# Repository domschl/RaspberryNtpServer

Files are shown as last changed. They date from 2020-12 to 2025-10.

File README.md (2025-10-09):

# GPS disciplined Stratum-1 NTP Server with Raspberry PI - a HowTo

Stratum-1 NTP time server with Raspberry Pi, GPS and Chrony: 

- how to build a precision time server.
- (optional) [how to add a 4x20 LCD to display](src) server status and GPS and PPS information.

<div align="right">
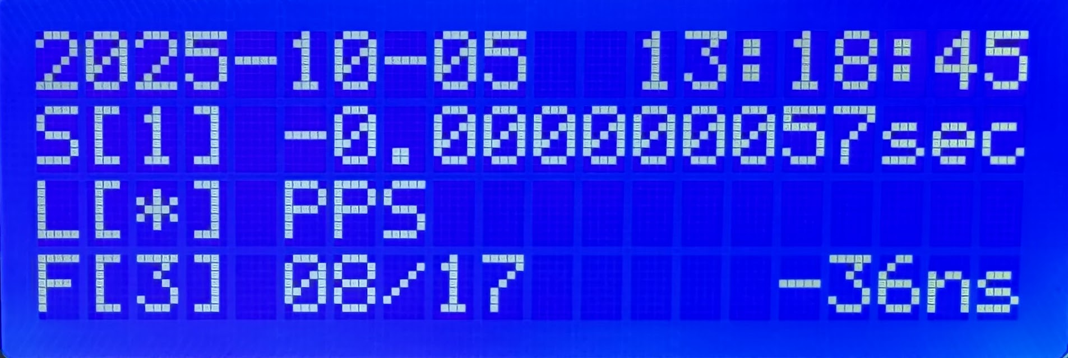
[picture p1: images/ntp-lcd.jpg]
<br>
<em>Optional display shows PPS lock, see <a href=https://github.com/domschl/RaspberryNtpServer/tree/main/src#notes-on-the-display-information>explanation</a></em>
</div>

## Requirements - Hardware

- Raspberry Pi

While you can use any model of Raspberry Pi to implement a Stratum-1 NTP server with GPS, the best choice
is Raspberry Pi 4, due to 1Gbit network interface and fast hardware for lowest possible latencies.

  - Using a Raspberry Pi 5 gives two additional advantages, but has changed the configuration of the serial port.

    - Support for the inbuilt hardware real time clock (RTC) that comes with the Raspberry Pi 5
    - Support for the PTP protocol, which allows to transmit precision time information via ethernet hardware
    - When connecting the GPS receiver via serial port, the new default is not to use the RX, TX pins on the 40pin connector, but the new three-pin UART connector. To use the 40-pin connector a special configuration is needed.

Both options are of limited advantage for most settings: the hardware clock is only useful for providing time during the first few seconds after boot (and if both GPS _and_ network are inaccessible), and PTP is a time standard requiring IEEE1588-enabled hardware everywhere and provides no advantages over NTP/chrony in most settings. Both however are documented below (See `chrony` configuration, PTP-chapter).

- GPS module

  * Adafruit GPS hat: [Adafruit ultimate GPS hat](https://www.adafruit.com/product/2324)
  * GPS module with serial output and PPS signal: [Adafruit GPS module](https://www.adafruit.com/product/746)
  * GPS module with USB, SMA connector and PPS: [Keystudio GPS module](https://wiki.keyestudio.com/KS0319_keyestudio_GPS_Module)
  * Cheap NEO6 modules: [Aliexpress NEO6](https://www.aliexpress.com/w/wholesale-neo6.html))

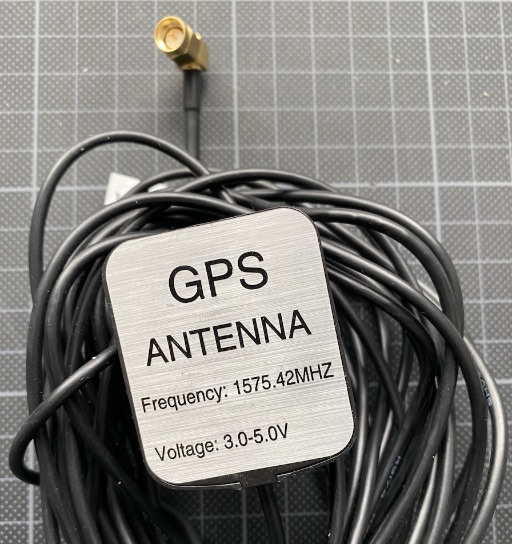
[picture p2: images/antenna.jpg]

  
* Active GPS antenna

When selecting a GPS antenna, make sure to get an active antenna with 3-5V power input. Passive antennas often look similar, but reception quality is far worse at similar cost.

### Antenna adapters

Some boards have uFL antenna connectors, whereas almost all external active antennas use SMA, so you might need an uFL to SMA adapter:

* [Adafruit uFL to SMA adapter](https://www.adafruit.com/product/851)
* [Various uFL to SMA adapters](https://www.aliexpress.com/item/4000166668788.html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,searchweb201602_,searchweb201603_)

### To check

#### Is external antenna selected?

Some GPS modules come with a passive antenna and and external antenna plug. Check the description of your board to find out what's needed to use the external antenna. The Keystudio GPS module listed above for example, requires the removal of capacitor C2 in order to activate the external antenna.

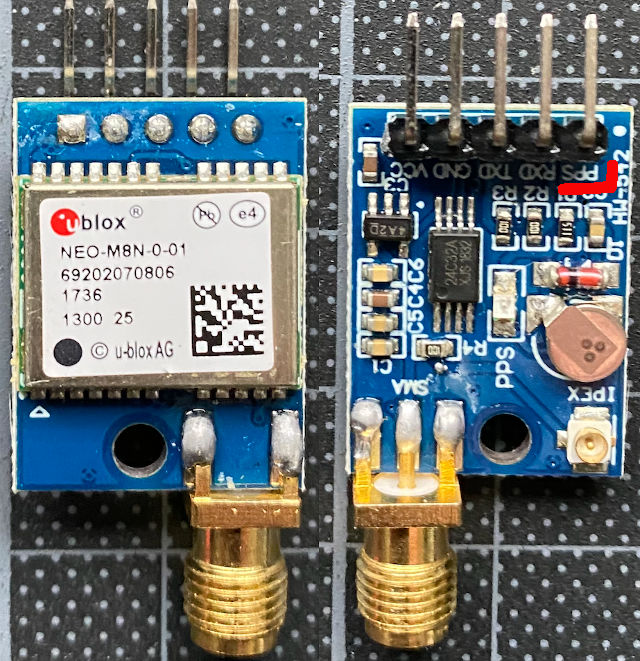
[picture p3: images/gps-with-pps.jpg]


#### PPS signal easily accessible?

Make sure your GPS module has an accessible output for the PPS signal. (Red mark on image)

If you are using a GPS Hat that plugs into the Raspberry IO connector, check the documentation to which GPIO pin the PPS signal is connected. Adafruit's Hat uses GPIO 4.

#### USB vs serial

When not using a Pi Hat, decide between USB- and serial connection.

USB-Connection:
* No extra cables for Vcc, GND, Tx, Rx are needed: both powersupply and communication goes over USB.
* No modification of Raspberry's serial console is needed, easier software installation
* Example: [Keystudio GPS module](https://wiki.keyestudio.com/KS0319_keyestudio_GPS_Module)

Serial connection:
* Usually cheaper, if a module is purchased.
* All Pi Hats use serial connections.
* Raspberry serial console needs to be disabled
* Sometimes, bluetooth needs to be disabled.
* Raspberry Pi 5 changed the default serial connection to the 3-pin UART connector by default.

### Recommended setup

* Raspberry PI 4 (or 5)
* Either GPS hat (e.g. adafruit ultimate GPS hat + uFL to SMA-Adapter) or USB-GPS-Module with PPS output (e.g. keystudio gps module)
* Active GPS antenna with SMA connector and 3-5V

### Most cost-efficient setup

NEO6 GPS modules are available at very low cost (1-2Eur) at chinese dealers (Aliexpress) and are perfectly usable as long as they allow connecting an active external GPS antenna and provide a PPS signal.

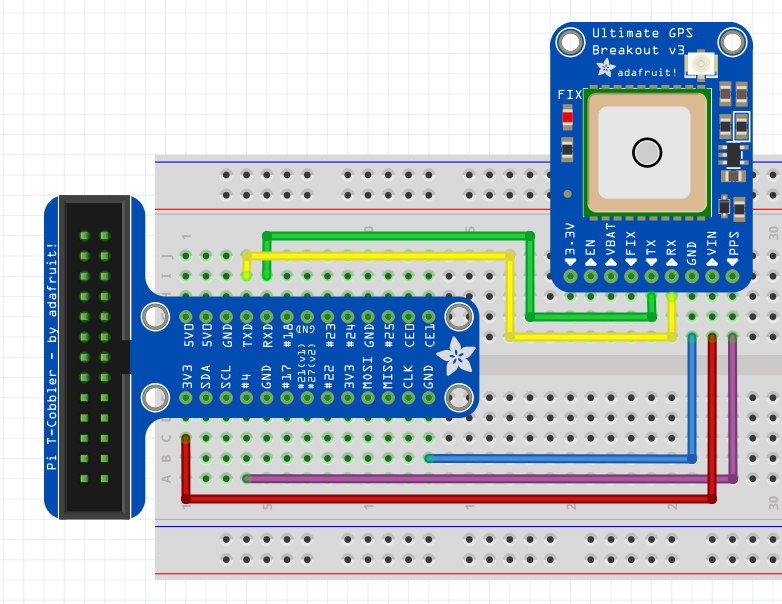
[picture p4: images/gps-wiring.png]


_Typical wiring between GPS module and Raspberry Pi connector._

> **Note:** If your GPS module is connected via USB, you only need to connect the PPS connector on the GPS module to GPIO 4 on the Raspberry. Power (Vin), Gnd and Tx/Rx are handled via USB.

> **Note:** The Raspberry Pi 5 has a new connector for the serial port that is used by default instead of the Pins RX, TX on the diagram:

#### Raspberry PI 5 serial connection changes

- Either use _new the three-pin UART connector_, which is used by default for serial communication,
- or reconfigure the serial ports by editing `/boot/firmware/config.txt` and adding the lines:

```
dtparam=uart0
dtparam=uart0_console
```

Documentation for those options is currently in a disarray for Raspberry Pi 5, so some research might be required. See discussion in [#6](https://github.com/domschl/RaspberryNtpServer/issues/6). Also this [video on Raspberry Pi 5 Serial Port](https://www.youtube.com/watch?v=27p4XHE3iyw) usage might be helpful.

### Test

**Before you continue with software:** At this point, the GPS module should be connected to the Raspberry Pi and the active antenna. Power up the Raspberry Pi, and check that the GPS module receives the GPS signal (the antenna must have unhindered access to the open sky, it does *not* work indoors!).

If reception is ok, a led ("FIX" or "PPS") should start blinking on your GPS module. 

Check the documentation for your specific hardware how "FIX" is signaled:

- The Adafruit module blinks once per second if there is no fix and once every 10 seconds when there is a fix.

### More information

* Adafruit has an excellent [GPS guide](https://learn.adafruit.com/adafruit-ultimate-gps) for their ultimate GPS module.

### Professional / Lab considerations: PTP precision time protocol (OPTIONAL)

If you are using laboratory equipment that uses PTP (precision time protocol) information (IEEE 1588), then you will need to use the Raspberry Pi 5 and make sure that your network switches are IEEE 1588 capable. Note that most consumer switches are not IEEE 1588 capable and cannot be used to set up a PTP network. See below (PTP chapter) for setup details and hardware tests.

PTP is completely optional and not required in a network in order to have excellent results with your Raspberry Pi NTP server!

## Software

> **Note:** _(Optional info)_ The original repository of `chrony` at <https://chrony.tuxfamily.org/> seems to be of low availability. In case of problems, use the mirror at <https://github.com/mlichvar/chrony)> if you want to reference the original `chrony` sources at some point.

### Raspberry Pi OS preparations

Supported are Raspberry Pi OS Bookworm and Trixie

#### Update Notes

If you are updating from 'Bookworm' to 'Trixie', and you are using the display, you will need to update the [display software](https://github.com/domschl/RaspberryNtpServer/tree/main/src) and its dependencies.

#### Serial port console (skip, if connected via USB)

If your GPS board is connected via serial connection (Rx/Tx), you need to "free up" Raspberry's serial port, which by default is used to connect a serial (debug) console. We need to disable that console to prevent it from interferring with the GPS module. 

This is *not* needed, if your module is connected via USB.

How to disable the serial console on Raspberry variies greatly depending on hardware revision and Linux flavour used. A few examples:

##### For Raspberry Pi 4 with Raspberry Pi OS:

1. Start raspi-config: `sudo raspi-config`.
2. Select option 3 - Interface Options.
3. Select option P6 - Serial Port.
4. At the prompt Would you like a login shell to be accessible over serial? answer 'No'
5. At the prompt Would you like the serial port hardware to be enabled? answer 'Yes'
6. Exit raspi-config and reboot the Pi for changes to take effect.

See ["Disable Linux serial console"](https://www.raspberrypi.org/documentation/configuration/uart.md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,Select%20option%20P6%20%2D%20Serial%20Port) at raspberrypi.org.

Older versions of `raspi-config` hide the same serial options under "Advanced options"

##### Other linux distributions and manual configuration

> **Note:** Recent Raspberry Pi OS has __moved__ the location of kernel config files from `/boot/` to `/boot/firmware/`. Adapt the following paths according to your OS version (If moved, a note is left at the old `/boot/` location.

1. Edit `/boot/firmware/cmdline.txt` and remove references to the serial port `ttyAMA0`. E.g. remove: `console=ttyAMA0,115200` and (if present) `kgdboc=ttyAMA0,115200`.
2. Disable getty on serial port. `sudo systemctl disable getty@ttyAMA0` or, on some Linux distris: `sudo systemctl disable serial-getty@ttyAMA0`
3. Enable uart in `/boot/firmware/config.txt`, add a line `enable_uart=1`
4. For RPI 3 or later disable bluetooth via overlay, add another line to `/boot/firmware/config.txt`: `dtoverlay=pi3-disable-bt-overlay`. In some versions, this is done by *enabling* the overlay `dtoverlay=pi3-miniuart-bt` which disables bluetooth and reestablishes standard serial.

See: ["Raspberry Pi 3, 4 and Zero W Serial Port Usage"](https://www.abelectronics.co.uk/kb/article/1035/raspberry-pi-3-serial-port-usage).  

#### Test serial / USB output of GPS

Do a `cat` on your serial port (e.g. `cat /dev/ttyS0`), or, for USB `cat /dev/ttyACM0` or `cat /dev/ttyUSB0`, and you should receive an output like:

```
$GPGGA,1413247.000,48432.1655,N,01342323.7322,E,1,06,1.340,2505.5,M,347.6,M,,*69
$GPGSA,A,3,123,303,248,205,037,415,,,,,,,1.59,1.340,0.90*049
```

## Setting up GPSD

Once you successfully receive output from your GPS module, next step is to install `gpsd` via your package manager.

For Raspberry Pi OS (and Ubuntu and Debian variants), that would be:

```bash
sudo apt install gpsd
```

Edit `/etc/default/gpsd`:

For serial connections (use your device name as tested above):

```
GPSD_OPTIONS="-n -G"
DEVICES="/dev/ttyS0"
USBAUTO="false"
```

For USB connections (again use your actual device name):

```
GPSD_OPTIONS="-n"
DEVICES="/dev/ttyACM0"
USBAUTO="true"
```

Enable and start `gpsd` with:

```
sudo systemctl enable gpsd
sudo systemctl start gpsd
```

Now use `cgps` or `gpsmon` to make sure that you are receiving GPS information and time.

`cgps` should display `Status: 3D fix (xx secs)`. Do not continue until you have a stable GPS fix.

## Setting up PPS

The serial or USB connection to the GPS module alone does not allow precise time synchronisation. The slow communication has latencies somewhere between 50ms to 200ms, much too high latency for precision time servers.

This is compensated by the PPS signal that is directly connected to Raspberry PI's GPIO 4 (you can use other GPIO pins, simply adapt this correpondingly below).

We need to enable a special kernel driver and overlay in order to receive this once-per-second GPS synchronised pulse as precisely as possible. The location of config files for kernel modules and options has changed recently (2024-03)!

### Current Raspberry Pi OS 'Bookworm' (since 2024-03) and 'Trixie' (since 2025-10)

You'll find that `/boot/config.txt` just contains a note that file content has moved to `/boot/firmware/config.txt`. 

1. Edit `/boot/firmware/config.txt` and add a line `dtoverlay=pps-gpio,gpiopin=4`. (Editing `cmdline.txt` is no longer necessary)
2. Edit `/etc/modules-load.d/raspberrypi.conf` and add two lines with `pps-gpio` and `pps-ldisc`, to load the required kernel modules

### Older versions of Raspberry Pi OS and other distris

if your `/boot/config.txt` does __not__ contain a note that content has moved to `/boot/firmware/config.txt`:

1. Edit `/boot/cmdline.txt` and add ` bcm2708.pps_gpio_pin=4` at the end of the line. (Might not be necessary)
2. Edit `/boot/config.txt` and add a line `dtoverlay=pps-gpio,gpiopin=4`. (Depending on your distri, either 1. or 2. is necessary, but it doesn't seem to hurt to do both).
3. Edit `/etc/modules-load.d/raspberrypi.conf` and add two lines with `pps-gpio` and `pps-ldisc`, to load the required kernel modules

After a reboot, a new device `/dev/pps0` should exist, and `dmesg` should show something like:

```
[    7.528565] pps_core: LinuxPPS API ver. 1 registered
[    7.530144] pps_core: Software ver. 5.3.6 - Copyright 2005-2007 Rodolfo Giometti <giometti@linux.it>
[    7.540372] pps pps0: new PPS source pps@4.-1
[    7.542012] pps pps0: Registered IRQ 166 as PPS source
[    7.550775] pps_ldisc: PPS line discipl43ine registered
```

Now use `ppstest` (you might need to install `pps-utils` or `pps-tools` depending on your distri):

`sudo ppstest /dev/pps0`

You should see an output like:

```
trying PPS source "/dev/pps0"
found PPS source "/dev/pps0"
ok, found 1 source(s), now start fetching data...
source 0 - assert 1606833766.999998552, sequence: 341090 - clear  0.000000000, sequence: 0
source 0 - assert 1606833767.999998573, sequence: 341091 - clear  0.000000000, sequence: 0
source 0 - assert 1606833768.999998751, sequence: 341092 - clear  0.000000000, sequence: 0
```

`assert` and `sequence` should both increment by 1 for each line.

Once you receive a PPS signal and GPSD is configured, continue.

### Access permissions for `/dev/pps0`

Some linux distribution only allow `root` to read or access `/dev/pps0`. This is no issue, if only root services want to access `/dev/pps0`. Note that recent versions of `chronyd` drop privileges after start, and then might not be able to access `/dev/pps0` anymore. See below for solutions (`udev` or running `chronyd` as root.)

### Timeouts with Raspberry Pi OS 64-bit 2023-03 onwards

**Note:** This problem seems to be fixed with current Raspberry Pi OS 'bookworm' and 'trixie' releases (2023-12 status).

`sudo ppstest /dev/pps0` yields:

```
found PPS source "/dev/pps0"
ok, found 1 source(s), now start fetching data...
source 0 - assert 1679340614.003464678, sequence: 84623 - clear  0.000000000, sequence: 0
time_pps_fetch() error -1 (Connection timed out)
```

See issue [6](https://github.com/domschl/RaspberryNtpServer/issues/6) for the ongoing discussion.

## Setting up Chrony as time-server

> **Note:** Before you setup `chrony`, make sure you completed `gpsd` configuration and that `gpsd` is running ok, and that you have a valid PPS signal at `/dev/pps0`.

> **Note:** Especially when using Raspberry Pi 5 (with new features PTP and RTC), it is recommended to use the standard Raspberry Pi OS, which comes with a chrony version, that is aware of the Raspberry Pi hardware.

Recent chronyd versions drop root privilege after start (check for the `-u` option in `chronyd.service` to see the user that will be used to run `chronyd`). If `/dev/pps0` is not accessible for that user, pps won't work. There are two solutions: either use a version of chronyd that doesn't drop privileges and runs as root, or setup a `udev` rule that allows access to `/dev/pps0` for the process-user of `chronyd`.

If you [compile](https://chrony.tuxfamily.org/doc/3.5/installation.html), [mirror](https://github.com/mlichvar/chrony/blob/master/doc/installation.adoc) `chrony` yourself, there is an option `--disable-privdrop` for `configure`. See `configure -h` for all options for building `chrony`.

### `udev` rules example

Udev rules are tricky and depend on the user of the `chronyd` process and the type of connection your are using.

Create a file `/etc/udev/rules.d/pps-sources.rules` starting with this example (which works with Raspberry Pi OS), which you will need to modify to your configuration:

```
KERNEL=="pps0", OWNER="root", GROUP="_chrony", MODE="0660"
KERNEL=="ttyS0", RUN+="/bin/setserial -v /dev/%k low_latency irq 4"
```

To activate those new `udev` rules, either reboot, or use: `sudo udevadm control --reload-rules && sudo udevadm trigger`.

This assumes `_chrony` being the user/group of the `chronyd` process (check with `ps aux | grep chronyd`) and a serial connection (here `/dev/ttyS0`) being used.[^1]

### Installation of `chrony`

Install `chrony`, an alternative NTP server that in my experience results in higher precision time servers than good old ntpd.

Make sure that no other time server (`ntdp`, `systemd-timedated`) is active, e.g.

```
sudo systemctl disable systemd-timedated
sudo systemctl stop systemd-timedated
```

Depending on you distri and chrony versione, the config is either `/etc/chrony/chrony.conf` or `/etc/chrony.conf`, edit the file and add two lines:

```
refclock PPS /dev/pps0 lock GPS
refclock SHM 0 refid GPS precision 1e-1 offset 0.0 delay 0.2 noselect
```

> **Note:** See [man chrony.conf](https://chrony-project.org/doc/4.4/chrony.conf.html) for more details

This uses a shared memory device `SHM` to get unprecise time information from GPSD (low precision, marked as `noselect`, so that chrony doesn't try to sync to serial time data). This unprecise time information is then synchronised with the much more precise PPS signal.

#### Additional Raspberry Pi 5 features

Verify that `chrony.conf` contains the following line (standard in Raspberry Pi OS version):

```
# This directive enables kernel synchronisation (every 11 minutes) of the
# real-time clock. Note that it can't be used along with the 'rtcfile' directive.
rtcsync
```

If you want to transmit PTP hardware timestamps via ethernet, add:

```
hwtimestamp *
```

See below for some more details on PTP.

#### All version, continued

Now enable and start `chrony`:

```
# Note: Some distributions use `chronyd` instead of `chrony`, so replace, if necessary:
sudo systemctl enable chrony
sudo systemctl start chrony
```

Verify that `chrony` started ok with `sudo systemctl status chronyd`. One possible error is a fatal message that `chronyd has been compiled without PPS support`. If that's the case (e.g. Manjaro ARM 64bit), you either need to [compile chrony yourself](https://chrony.tuxfamily.org/doc/2.4/installation.html), [mirror](https://github.com/mlichvar/chrony/blob/master/doc/installation.adoc), or switch to another distri.

Then start the chrony console with `chronyc`. At the `chronyc>` prompt, enter:

`sources`

```
chronyc> sources
210 Number of sources = 6
MS Name/IP address         Stratum Poll Reach LastRx Last sample               
===============================================================================
#* PPS0                          0   4   377    13   -138ns[ -108ns] +/-  120ns
#? GPS                           0   4   377    13  -4624us[-4624us] +/- 2148us
^- sismox.com                    3  10   377    15   -179us[ -179us] +/-   81ms
^- ntp.fra.de.as206479.net       2  10   377   749  +4235us[+4238us] +/-   16ms
^- mail.trexler.at               2  10   377  1114  +1190us[+1193us] +/-   13ms
^- ntp2.hetzner.de               2  10   377    59   -411us[ -411us] +/-   32ms
chronyc> 
```

**Note:** See [man chronyc](https://chrony-project.org/doc/4.0/chronyc.html) for more details

<div align="right">
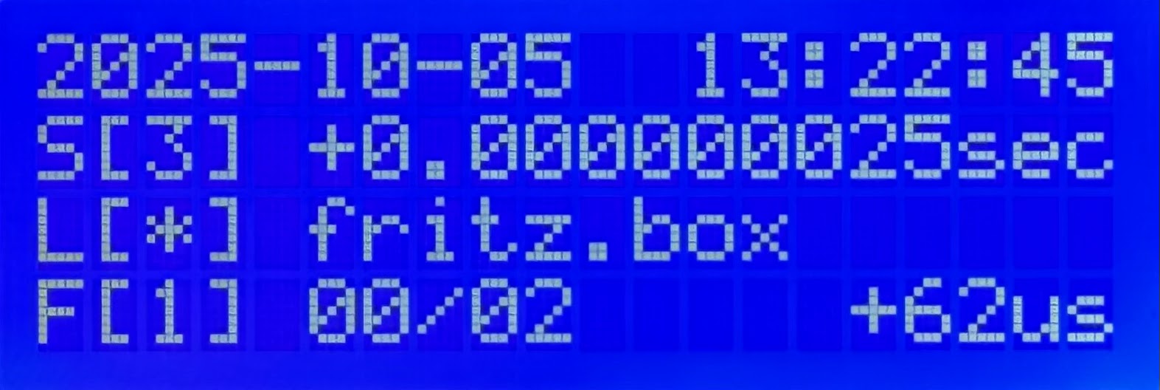
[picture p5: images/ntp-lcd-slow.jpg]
<br>
<em>Before PPS lock, stratum 3</em>
</div>

If all went well, you should see a `PPS` device marked with `#*`, indicating the active time source. Error should be in nanosecond range (`-138ns[ -108ns] +/-  120ns`). `#?` indicates an unusable time source, `^-` a usable but unused source.

### Synchronizing the offset between serial time information and PPS

The PPS signal is only used, if the divergence between the slow serial/USB time information and the precise PPS signal is less than 200ms. If your PPS device stays on `#?` (unusable), and you are sure that gpsd is receiving valid GPS signals and `ppstest` shows a correct PPS signal, then we need to tune the offset between serial time information and PPS. 

In `chronyc`, enter `sourcestats`

```
chronyc> sourcestats
210 Number of sources = 9
Name/IP Address            NP  NR  Span  Frequency  Freq Skew  Offset  Std Dev
==============================================================================
...
GPS                        40  22   626     -4.310      9.467    512ms  2474us
...
```

the important field is `offset` of `GPS`: if that is larger 200ms, PPS cannot sync to GPS.

Wait a few minutes for the offset to stabilize, note it's value, and edit `/etc/chrony.conf` (or `/etc/chrony/chrony.conf`), and change the offset in the second line with the value above, converted to seconds (512ms are 0.512 sec in this case):

```
refclock PPS /dev/pps0 lock GPS
refclock SHM 0 refid GPS precision 1e-1 offset 0.512 delay 0.2 noselect
```

<div align="right">
<br>
<em>After PPS lock, stratum 1</em>
</div>

> **Note:** A value of `offset 0.0` seems to prevent synchronisation for some versions of chrony, so use some small non-zero value instead, if a value close to 0 is required for your installation.

Restart `chrony` with `sudo systemctl restart chronyd`, and check `chronyc` again:

After some time the output of `sourcestats` should show a much better offset for GPS:

```
chronyc> sourcestats
210 Number of sources = 9
Name/IP Address            NP  NR  Span  Frequency  Freq Skew  Offset  Std Dev
==============================================================================
PPS0                       12   5   179     +0.000      0.003     +1ns   102ns
GPS                        40  22   626     -4.310      9.467  -8600us  2474us
```

and `sources` should now show PPS as active, marked with `#*`.

Use `chronyc` and command `tracking` to get information about the precision of your new time server:

```
chronyc> tracking
Reference ID    : 50505330 (PPS0)
Stratum         : 1
Ref time (UTC)  : Tue Dec 01 15:17:22 2020
System time     : 0.000000032 seconds slow of NTP time
Last offset     : -0.000000059 seconds
RMS offset      : 0.000000103 seconds
Frequency       : 2.167 ppm fast
Residual freq   : -0.000 ppm
Skew            : 0.005 ppm
Root delay      : 0.000000001 seconds
Root dispersion : 0.000025110 seconds
Update interval : 16.0 seconds
Leap status     : Normal
```

* For more information, check the [chrony PPS documentation](https://chrony.tuxfamily.org/faq.html#_using_a_pps_reference_clock), [mirror](https://github.com/mlichvar/chrony/blob/master/doc/faq.adoc#using-pps-refclock)

### Making you new precision time server available on the network

By default, chrony allows only local access, use `allow` in `/etc/chrony.conf` to allow access in your local network, e.g.:

```
allow 192.168/16
```

To be able to administer the chrony time server over the net, add:

```
cmdallow 192.168/16
```

### Remote testing

The tool `sntp` (available by default on macOS, part of the `ntp` package for most linux distributions)
allows for simple remote testing:

> **Note:** when installing `ntp` for getting access to the `sntp` tool, make sure that you do not accidentally activate the `ntp` server which will conflict with your chrony installation.

```bash
sntp <ip-or-hostname-of-raspberry-chrony-server>
```

yields (mac connected via WLAN):
```bash
sntp chronotron
# Output:
+0.011341 +/- 0.002986 chronotron 192.168.178.3
```

More information is available with `sntp -d`

```bash
sntp -d chronotron
# Output:
sntp_exchange {
        result: 0 (Success)
        header: 24 (li:0 vn:4 mode:4)
       stratum: 01 (1)
          poll: 00 (1)
     precision: FFFFFFE8 (5.960464e-08)
         delay: 0000.0001 (0.000015259)
    dispersion: 0000.000B (0.000167847)
           ref: 50505300 ("PPS ")
    ...
}
```

Interesting information is for example:

- `ref: xx.. ("PPS")`
- `precision: (5.9e-08)`

### Raspberry Pi 5 and the PTP precision time protocol via ethernet  [OPTIONAL for SPECIAL SETTINGS]

> **Note:** The PTP precision time protocol (IEEE 1588) is of limited use for home networks, it requires that every component (server, network switch, client) have hardware support for IEEE 1588 which is not the case for most consumer hardware. You cannot use PTP if a single component does not support it.

An excellent overview over PTP, it's relation to NTP can be found at Redhat's [_combining ptp and ntp_](https://www.redhat.com/en/blog/combining-ptp-ntp-get-best-both-worlds) article.
If you are not in a professional lab environment, _you might not need PTP at all!_

#### Preparations

You can verify that hardware timestamping is active by executing `sudo systemctl status chrony` right after start of chrony. You should see something like:

```
Dec 20 15:17:15 chronotron chronyd[9525]: chronyd version 4.3 starting (+CMDMON +NTP +REFCLOCK +RTC +PRIVDROP +SCFILTER +SIGND +ASYNCDNS +NTS +SECHASH +IPV6 -DEBUG)
Dec 20 15:17:15 chronotron chronyd[9525]: Enabled HW timestamping on eth0
```

To verify if a chrony client or server can support the PTP protocol, use:

```bash
ethtool -T eth0
```

You should see something like:

```
Time stamping parameters for eth0:
Capabilities:
        hardware-transmit
        software-transmit
        hardware-receive
        software-receive
        software-system-clock
        hardware-raw-clock
PTP Hardware Clock: 0
Hardware Transmit Timestamp Modes:
        off
        on
        onestep-sync
Hardware Receive Filter Modes:
        none
        all
```

Required are the `hardware-transmit` and `hardware-receive` options.

#### PTP software

Make sure the kernel module `ptp` is loaded (`sudo modprobe ptp`). In addition, you will need `linuxptp` on both server and client. On the
raspberry, it can be installed with `sudo apt install linuxptp`

On the raspberry server:

```
sudo ptp4l -i eth0 ptp0 -m -2
```

The ptp server should start and output something like:

```
ptp4l[6491.320]: selected /dev/ptp0 as PTP clock
ptp4l[6491.364]: port 1: INITIALIZING to LISTENING on INIT_COMPLETE
ptp4l[6491.364]: port 0: INITIALIZING to LISTENING on INIT_COMPLETE
ptp4l[6498.761]: port 1: LISTENING to MASTER on ANNOUNCE_RECEIPT_TIMEOUT_EXPIRES
ptp4l[6498.761]: selected local clock d83add.fffe.b1d67a as best master
ptp4l[6498.761]: port 1: assuming the grand master role
```

Now, on a client that has a network card with IEEE 1588 support (check with `ethtool -T eth0` that hardware-transmit is supported) and is connected either directly or via a PTP-IEEE 1588 enabled switch (hint: most consumer network switch _do not support the required protocol_!):

again make sure module `ptp` is loaded, install `linuxptp` and:

```
sudo ptp4l -i enp86s0 -m -2 -s
```

the `-s` option enables slave mode for the client.

If it works, you should see something like:

```
ptp4l[82232.615]: selected /dev/ptp0 as PTP clock
ptp4l[82232.689]: port 1 (enp86s0): INITIALIZING to LISTENING on INIT_COMPLETE
ptp4l[82232.689]: port 0 (/var/run/ptp4l): INITIALIZING to LISTENING on INIT_COMPLETE
ptp4l[82232.689]: port 0 (/var/run/ptp4lro): INITIALIZING to LISTENING on INIT_COMPLETE
ptp4l[82233.617]: port 1 (enp86s0): new foreign master d83add.fffe.b1d67a-1
ptp4l[82237.617]: selected best master clock d83add.fffe.b1d67a
ptp4l[82237.617]: port 1 (enp86s0): LISTENING to UNCALIBRATED on RS_SLAVE
ptp4l[82239.619]: master offset   59823 s0 freq  -51831 path delay    4413
ptp4l[82240.618]: master offset   59749 s1 freq -2154985 path delay   4159
ptp4l[82241.618]: master offset   59733 s2 freq  +91748 path delay   4159
```

If you get any `received SYNC without timestamp` or similar with `DELAY`, then somewhere in your transmission chain there is non-IEEE 1588 hw, and the sync doesn't work.

### Further optimizations in `chrony.conf`

* `lock_all` to make sure chrony is always in memory.
* `local stratum 1` to signal precision time.
* `allow` without any address simply allows all networks. (Including external access, if your machine is connected to the internet!)

For more, check the [official chrony documenation](https://chrony.tuxfamily.org/doc/4.0/chrony.conf.html), [mirror: chrony.conf](https://github.com/mlichvar/chrony/blob/master/doc/chrony.conf.adoc).

## Add a 4x20 hardware LCD display

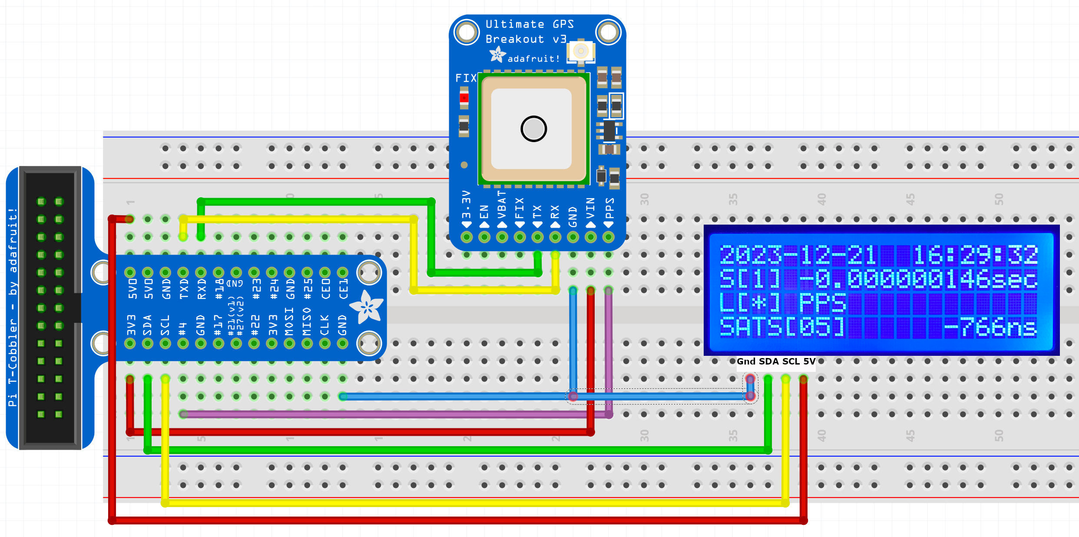
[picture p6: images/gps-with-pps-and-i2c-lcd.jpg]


Optionally, you can use [this sub-project to a status display to the Raspberry Pi](src).

## History

- 2025-10-09: Support for Adafruit I2C hardware using MCP23008 added, thanks @Bigjohn4 for testing support.
- 2025-10-05: Changed display software to use python3-gps library, thanks [rglidden](https://github.com/rglidden)
- 2024-04-30: Changes to Raspberry Pi 5 serial Port configuration, see [6](https://github.com/domschl/RaspberryNtpServer/issues/6), thanks @aGGreSSiv for figuring out the issue!
- 2024-03-06: Update: location of `/boot/config.txt` has changed to `/boot/firmware/config.txt`. Thanks to @Nebulosa-Cat for the information!
- 2023-12-21: Cleanup for the display software, display current stratum level (thanks @Lefuneste83, see [#7](https://github.com/domschl/RaspberryNtpServer/issues/7)), implemented logging.
- 2023-12-20: Raspberry 5 and suport for RTC and PTP precision time protocol how-tos.
- 2023-07-11: Documentation fixes (thx. @glenne), see [#4](https://github.com/domschl/RaspberryNtpServer/issues/4) for details. Mirror links for `chrony` added.
- 2023-02-24: Added information by @cvonderstein on initial `offset 0.01` and `udev` rules, see [#1](https://github.com/domschl/RaspberryNtpServer/issues/1) for details.
- 2023-01-09: Code for 4x20 LCD display for NTP server PPS state added.

### References

- [`chrony` documentation](https://chrony-project.org/documentation.html)
- [`chrony` documentation (mirror)](https://github.com/mlichvar/chrony/tree/master/doc)

[^1]: Thanks @cvonderstein for providing this information, see [#1](https://github.com/domschl/RaspberryNtpServer/issues/1) for further discussion.

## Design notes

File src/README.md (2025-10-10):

# Simple 4x20 LCD display for Raspberry Pi NTP Server

The display shows current NTP time and date, the PPS signal locking state, Stratum level, the offset to the NTP time, the number of satellites that are currently used, and, if no PPS lock is available, alternatively the address of the time server used.

If you see an address of some time server, PPS lock is not (yet) working.

Note: the main script `chronotron.py` defines a `start_time` and an `end_time`, used to switch on the LCD backlight (at `start_time`) and switch it off at (`end_time`). If you want permanent backlight, simply set `start_time` and `end_time` to `None`.

## Hardware requirements

- Display: HD44780 2004 LCD Display 4x20 characters with I2C interface (address 0x27 is assumed by the code), use for example:
  - Adafruit [LCD 4x20](https://www.adafruit.com/product/198) and [I2C Adapter](https://www.adafruit.com/product/292), description: (https://learn.adafruit.com/i2c-spi-lcd-backpack). Advantage: Stemma QT adapter (QWIIC) that can be also added to [Raspberry PI](https://www.adafruit.com/product/4463#:~:text=The%20SparkFun%20Qwiic%20or%20Stemma%20QT%20SHIM%20for,QT%20or%20Qwiic%29%20connector%20to%20your%20Raspberry%20Pi.) for clean cabling. Note: uses MCP23008 chip requires changes to the default configuration.
  - Amazon kit [sunfounder kit](https://www.amazon.com/SunFounder-Serial-Module-Arduino-Mega2560/dp/B01GPUMP9C)
  - AliExpress kit [TZT Five Star](https://de.aliexpress.com/item/1005001679675215.html

Make sure that I2C is enable on your Raspberry PI.



Connect the LCD Display the GND, 5V and SDA and SCL pins or the Raspberry PI.

> **Note:** Raspberry PI uses 3.3V logic, and the LCD Display is connected to 5V. This _should_ not be a problem, since the lcd just receives from Raspberry PI. If you want to be on the safe side, either try to power the LCD with **3.3V**, or use a **logic-level-converter**.

> **Note:** if your display uses a different address than `0x27`, 
or if you are using a very old Raspberry that still uses `sm_bus=0`, you need to adapt:

```python
lcd = LcdDisplay(sm_bus=1, i2c_addr=0x27, cols=20, rows=4)
```

Old Raspis use `sm_bus=0`.

> **Note:** if the LCD screen looks inverted or too faint, or no output is visible at all, use the potentiometer on the adapter-board to adjust the contrast.

## Software requirements

> **Note:** Standard Raspberry Pi OS (tested with 'Bookworm' and 'Trixie') is recommended and used below

This project uses `python3-gps` and `python3-smbus` (already available on some distributions).

### Python dependencies

Install the python GPS library and smbus, if they are not already installed on your system:

```bash
sudo apt install python3-gps python3-smbus
```

Note: Previous versions of this software relied on `gps-py3`, which was not included in Raspberry Pi OS python libraries and therefore required a venv. This is no longer required. See [PR9](https://github.com/domschl/RaspberryNtpServer/pull/19) for more details on the changes. If you previously used a venv, you might need to update your systemd service file and remove the venv directories.

Note: Trixie requires update to the new dependencies, otherwise GPS satellite status is broken!

## Installation of chronotron software

0. Clone the repository

```bash
git clone https://github.com/domschl/RaspberryNtpServer
cd RaspberryNtpServer/src
```

1. Adapt configuration

Check the beginning of the file `chronotron.py`, it contains a few parameters that can be adapted:

```python
#------- CONFIGURATION PARAMETERS -----------------------
# start_time and end_time switch the display off during night-time.
# Set both to None for always-on
start_time:str|None = "07:00"
end_time:str|None = "21:00"
# I2C address of the display, usually between 0x20 (Adafruit default) and 0x27 (all others)
i2c_address_display:int = 0x27
# Set to True for Adafruit I2C adapter which uses MCP23008 chip. Enables Adafruit specific connections
# Set to False for all others which use PCF8574 
adafruit_i2c_hardware:bool = False
# Display time as UTC
display_utc_time:bool = False
# LCD display update timing: False: default, slow according to spec,
# True: update faster, low latency, exceeds specs
lcd_latency_overdrive:bool = False
# ---------------------------------------------------------
```

For Adafruit hardware that uses the MCP23008 chip and a (default) address of 0x20 make the following changes:

```python
i2c_address_display:int = 0x20
adafruit_i2c_hardware:bool = True
```

If you don't want backlight to switch off during the night, set:

start_time:str|None = None
end_time:str|None = None

Otherwise adapt the times to your liking, using 24h times and format "HH:MM"

If you want to display the time as UTC, set
# Display time as UTC
display_utc_time:bool = True

You can try to reduce LCD display latency by setting:
lcd_latency_overdrive:bool = True

2. Copy the python files to `/opt/chronotron`:

```bash
mkdir /opt/chronotron
chown -R $USER:$USER /opt/chronotron
# Now copy:
cp button.py chronotron.py i2c_lcd.py /opt/chronotron
```

3. Install the systemd service

```bash
sudo cp chronotron.service /etc/systemd/system
```

Enable the systemd server `chronotron` with:

```bash
sudo systemctl enable chronotron
sudo systemctl start chronotron
```

Check, if everthing works:

```bash
sudo systemctl status chronotron
```

If everything worked, the output should be something like:

```
chronotron.service - Display chrony statistics on 4x20 LCD
     Loaded: loaded (/etc/systemd/system/chronotron.service; enabled; preset: disabled)
     Active: active (running) since Tue 2022-10-25 14:44:17 CEST; 2 months 15 days ago
   Main PID: 370 (chronotron.py)
      Tasks: 2 (limit: 3921)
        CPU: 3d 5h 34min 24.354s
     CGroup: /system.slice/chronotron.service
             └─370 /usr/bin/python /opt/chronotron/chronotron.py

Dec 21 09:38:37 chronotron systemd[1]: Started chronotron.service - Display chrony statistics on 4x20 LCD.
Dec 21 09:38:37 chronotron chronotron.py[2628]: INFO:Chronotron:Chronotron version 2.0.0 starting
Dec 21 09:38:37 chronotron chronotron.py[2628]: INFO:Chronotron:Chrony aquired lock to time source
Dec 21 09:38:37 chronotron chronotron.py[2628]: INFO:Chronotron:Chrony receiving time source from PPS
Dec 21 09:38:37 chronotron chronotron.py[2628]: INFO:Chronotron:Chrony stratum level changed to 1
Dec 21 09:38:37 chronotron chronotron.py[2628]: INFO:Chronotron:Chrony locked to high precision GPS PPS signal
```

## Notes on the display-information

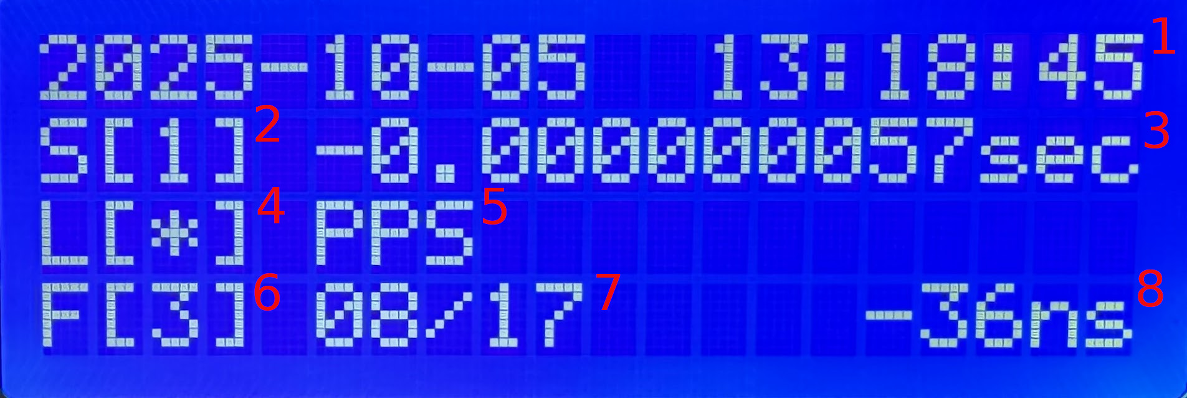
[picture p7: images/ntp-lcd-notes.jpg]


1. Time and date according to NTP
2. The current stratum level is displayed as `S[1]` for stratum level 1. 
3. Shows the output of `chronyc tracking`, entry `system time`, the time difference to the NTP reference (see below for further information).
4. `L[ ]` no lock, `L[*]` lock. A lock (`*`) indicates that time synchronisation is established, either via remote NTP servers or GPS + PPS
5. `PPS` signales that the lock is active using GPS and PPS, the server is in high-precision stratum 1 mode. If instead a hostname is displayed, then PPS is NOT active, and the network is used for time synchronisation, resulting in lower precision.
6. **New** `F[n]`, `n` is the GPS fix type: '-': unknown, 1: no fix, 2: 2D fix, 3: 3D fix.
7. **New** `nn/mm`, nn: used satellites, mm: total seen satellites, including unused ones.
8. Shows output of `chronyc sources`, the last column, "adjusted offset", of the currently active source, which is the estimated error (see below for further information)

### Further information and references

#### `chronyc tracking`

Marked with >>>nnnn.nnnn<<< is the information displayed at (2).
Here, the system is 0.000000100 seconds faster than NTP ref.

```
chronyc tracking
# sample output:
Reference ID    : 50505300 (PPS)
Stratum         : 1
Ref time (UTC)  : Tue Jul 11 07:22:07 2023
System time     : >>>0.000000100<<< seconds fast of NTP time
Last offset     : +0.000000030 seconds
RMS offset      : 0.000010080 seconds
Frequency       : 10.392 ppm fast
Residual freq   : -0.006 ppm
Skew            : 0.005 ppm
Root delay      : 0.000000001 seconds
Root dispersion : 0.000384213 seconds
Update interval : 16.0 seconds
Leap status     : Normal
```

#### `chronyc sources`

Marked with `>>>nnn<<<` is the information displayed at (6).
Here the estimated error of the PPS signal is 591ns

```
chronyc sources -v
# sample output with explanation (-v paramenter):
  .-- Source mode  '^' = server, '=' = peer, '#' = local clock.
 / .- Source state '*' = current best, '+' = combined, '-' = not combined,
| /             'x' = may be in error, '~' = too variable, '?' = unusable.
||                                                 .- xxxx [ yyyy ] +/- zzzz
||      Reachability register (octal) -.           |  xxxx = adjusted offset,
||      Log2(Polling interval) --.      |          |  yyyy = measured offset,
||                                \     |          |  zzzz = estimated error.
||                                 |    |           \
MS Name/IP address         Stratum Poll Reach LastRx Last sample               
===============================================================================
#? GPS                           0   4     0   780    +43ms[  +43ms] +/-  200ms
#* PPS                           0   4     0   782   +186ns[ +217ns] +/-  >>>591ns<<<
^? 2003:2:2:140:194:25:134:>     2  10   377   340   +141us[ +141us] +/-   17ms
^? time.ontobi.com               2  10   377   264   +139us[ +139us] +/-   13ms
^? bblock.dev                    2  10   377   631   +209us[ +209us] +/-   12ms
^? time01.nevondo.com            2  10   377   721   +181us[ +181us] +/-   28ms
^? static.33.250.47.78.clie>     3  10   377  1168   -191us[ -213us] +/-   15ms```
```

#### References

- <https://access.redhat.com/documentation/en-us/red_hat_enterprise_linux/8/html/configuring_basic_system_settings/using-chrony_configuring-basic-system-settings>
- [chronyc documentation](https://github.com/mlichvar/chrony/blob/master/doc/chronyc.adoc)

## Notes:

The `chronotron.py` systemd service checks periodically `chronyc` for NTP statistics (`chronyc` must be in the path!), and uses `gpsd` for the GPS statistics (number of satellites).

- `button.py` is currently not used.
- `i2c_lcd.py` is a buffered driver for the LCD display.
- `chronotron.service` is the systemd service file.

## History

- 2025-10-09: Support Adafruit's hardware that uses a different I2C chip, the MCP23008
- 2025-10-08: Add I2C port check on display initialization
- 2025-10-05: Update of dependencies, Trixie support (thanks [rglidden](https://github.com/rglidden))

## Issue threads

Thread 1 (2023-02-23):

Offset value of 0.0 prevents usage of GPS

cvonderstein, 2023-02-23:
Hey,

as written in the title, the offset value of `0.0` for the GPS refclock stored in `/etc/chrony/chrony.conf` (which seems to be the newer path for the config) prevents the usage of GPS as reference time. The same was discussed [here](https://chrony-users.chrony.tuxfamily.narkive.com/xJPF5Ph9/chrony-does-not-select-pps-source).

Setting it to `0.1` fixed it, I'm not sure if that breaks something or lowers the accuracy, but afterwards it at least worked for me. Maybe you want to include this in your Readme?

Addition after writing this: I saw that you mentioned correcting the offset in the config later, but for me the problem was that the GPS didn't get selected as reference clock in the first place (as it should have been as described in https://github.com/domschl/RaspberryNtpServer#setting-up-chrony-as-time-server), and the `Last sample` shown for PPS was always 0. The linked section is where I got stuck, and I didn't even get to the point of having GPS selected as the main time source.

Also, while we're at it, it would be nice to have the corresponding `udev` rules included (as figuring out how to do it when you've never worked with them before is quite pain). Just as quick reference (if you want to copy it): `/etc/udev/rules.d/pps-sources.rules` should contain

```
KERNEL=="pps0", OWNER="root", GROUP="_chrony", MODE="0660"
KERNEL=="ttyS0", RUN+="/bin/setserial -v /dev/%k low_latency irq 4"
```

This assumes the user of the `chronyd` process to be `_chrony`, which can be found out using `ps aux | grep chronyd`. Also, I'm using the serial connection here, otherwise `ttyS0` probably needs to be changed. To reload udev rules without reboot, run

```
sudo udevadm control --reload-rules && sudo udevadm trigger
```

Both cost me quite some time figuring out, so I would be happy if you include both improvements in your Readme File.

Closed 2023-02-24.

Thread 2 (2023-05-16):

Error about LCD sub project

Nebulosa-Cat, 2023-05-16:
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
I get something wrong like permission denied 、ModuleNotFoundError: No module named 'gpsd'、ModuleNotFoundError: No module named 'smbus'...

looks like somethin wrong between pip and pip3 ?

system: Pi OS 64 Lite

domschl, 2023-05-17:
You need two python packages, `smbus` and `gpsd-py3`.
I don't know Pi OS 64 Lite, but it might be good to first check if your package manager has packages with names `python3-smbus`, `python-gpsd-py3` or `python-smbus`, `python-gpsd-py3`.

If not, you can always use `pip` (`pip` and `pip3` seem to point to the same pip on your machine):

```bash
pip install smbus gpsd-py3
```

Then, before restarting the service, you could manually start the program for test:

```bash
python chronotron.py
```

You might need to use `sudo` by typing: `sudo python chronotron.py` depending on the access rights for smbus.

If you still get `module not found` errors, while having installed them with pip, you might need to repeat the installation of both modules with `sudo pip install smbus gpsd-py3`. Note that installing pip modules with `sudo` should only be done, if the modules are not available via your package manager, so check that first.

Also make sure that you are using `python3`. Simply start `python` and check the version number, it should start with `3....`.

Once you get it running, I will update the documentation, so please let me know how it goes.

Nebulosa-Cat, 2023-05-17:
>

I first check my python version ( `python -V` is 2.x.x and `python3 -V` is 3.9.2
so I do `nano ~/.bashrc` and `alias python=/usr/bin/python3.9`
now `python -V` is 3.9.2 now

and install smbus and gpsd-py3

but still get some wrong like this
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

(by the way, if use windows copy python file raw content on github and save as .py file, it will show error as "^M" at the end, looks a interpreter error, maybe need to mention just download all github file zip and use sftp upload file to Pi or use git command direct to Pi)

domschl, 2023-05-17:
That's progress: the software is now installed, but smbus fails to open.

Possible causes:

- Which raspberry hardware are you using (old raspis need different bus number)?
- Did you enable SMBUS and I2C using `raspi-config`?
- Did you try to run `sudo python chronotron.py`?

Nebulosa-Cat, 2023-05-17:
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

(before and after I open i2c in setting are same) `sudo python chronotron.py` :
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

Yes I'm not open i2c setting ( i'm only changed serieal port before), now it work and function normaly when manually use `python chronotron.py`

but if I use `sudo systemctl enable chronotron` and `sudo systemctl start chronotron` it will got `Permission denied`

if use `sudo chmod +x chronotron.py`

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

it will return fail same as use `sudo python chronotron.py`

domschl, 2023-05-17:
I've updated `chronotron.py` in the repository: That line that causes an error (`def exec(cmd):`) may have happened because of a name-clash with python's standard libs. Strangely, I never encounter this.

I've renamed the function to (hopefully!) prevent the error.

Please try again with that updated version.

Nebulosa-Cat, 2023-05-17:
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

looks still bugged, but if simply run `python chronotron.py` it work.

domschl, 2023-05-17:
So that's a good hint: the default python version for root is the old python2, which won't work!

Try an explicit path for python to start:

```bash
# verify version:
sudo /usr/bin/python
# Is there an explicit python3?
sudo /usr/bin/python3
# (results of both should be python 3.9)
# Then try again (if it exists, use `/usr/bin/python3` instead of `/usr/bin/python`
sudo /usr/bin/python chronotron.py
```

Then, if that works, we can change the `chronotron.service` file to use an explicit path.

If that works, edit the service file,

Nebulosa-Cat, 2023-05-17:
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

all fix, thank you very much, look nothing wrong now !

domschl, 2023-05-17:
Excellent!

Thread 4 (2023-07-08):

Documentation Suggestions

glenne, 2023-07-08:
Great tutorial!  I just got mine up and running.  Here's a few suggestions:

- Typo - Several references (4) to systemctl ... chronyd.  This should be just 'chrony', not 'chronyd'
- Typo - 'install gpsd via your **packet** manager.' should be 'install gpsd via your **package** manager.'
- Suggest including an example on how to install the first time an install is needed - 'sudo apt-get install gpsd'
- When adding allow 192.168/16 to chronyd.conf, one can omit the IP address and it will allow connections from any connected interface.
- A simple test from another computer can test connectivity.  On a mac, ```sntp <ip address>```, or verbose ```sntp -d <ip address>``` and it will show PPS0 being used.
- Documentation says 'If reception is ok, a led ("FIX" or "PPS") should start blinking on your GPS module.' On my Adafruit module, it blinks 1x/second if not fix and once every 10 seconds when there is a fix.

Bob-VK6ZGN, 2023-07-10:
Yes Great tutorial! I just got mine up and running.
Also using  Adafruit module and Rpi3 64bib Rasberian OS   All good
with one exception    Not sure what I am doing wrong But for SATS I just get [ -- ] when I have + 20 connected

any thoughts

domschl, 2023-07-10:
@glenne: thanks for the list, will work on that during the next days
@Bob-VK6ZGN : probably something going wrong with the `gpsd-py3` dependency. Maybe open a separate issue for this, and we can try to track this down?

glenne, 2023-07-10:
It would also be a bonus to explain what the time offset fields mean on the LCD.  e.g. NTP: and SATS

domschl, 2023-07-11:
@glenne : I've added most of the suggestions:
some remarks:
- on some distris it is actually service 'chronyd', so I added both.
- `allow` without address (and especially `cmdallow` without) can lead to unexpected [results](https://github.com/domschl/RaspberryNtpServer#further-optimizations-in-chronyconf)

Thanks for the input!

I leave this open for further discussion. Feel free to close, if completed for now.

glenne, 2023-07-11:
Looks great!  Thanks for the update.

Closed 2023-07-11.

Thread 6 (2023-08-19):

Fix for ppstest timeout

fitzy89, 2023-08-19:
With a recent update to Raspbian, it's necessary to add `arm_64bit=0` to /boot/config.txt and reboot in order to get the pps working

domschl, 2023-08-19:
I am using PPS with `arm_64bit=1` but with Manjaro. So there's probably something else going on? Maybe the access rights for `/dev/pps0` changed? Do you have some more information (e.g. `dmesg` logs?)

fitzy89, 2023-08-19:
I was following your guide using the latest Raspbian and at the point of running ppstest I was seeing timeout errors, the same issue as mentioned in this post - https://github.com/raspberrypi/linux/issues/5430 which is what led me to the above solution which seems to work fine for me.

domschl, 2023-08-20:
Interesting! A kernel bug seems to be the cause: a patch intended for 32bit got wrongly applied to 64bit. Did you try the fix suggested in:

<https://github.com/raspberrypi/linux/issues/5430#issuecomment-1557295230>

namely:

```bash
sudo rpi-update pulls/5478
```

which pulls a new 64bit kernel patch? (so `arm_64bit=1` for the patched kernel).

OdessaEyes, 2023-08-21:
For me it didn't work.
Rpi3b, 5.15.76-v7+ #1597 SMP armv7l GNU/Linux, Raspbian GNU/Linux 11 (bullseye)
sudo rpi-update or/and add arm_64bit=0 to /boot/config.txt  didn't solve the problem.

If you have any other ideas I'd be happy to try.

domschl, 2023-08-21:
@OdessaEyes : You might be encountering a different problem, since you are running 32bit Raspbian.
If your error is not timeouts on ppstest with messages like:
```
time_pps_fetch() error -1 (Connection timed out)
```
then it might be best to open a separate bug report describing what you tried?

Nebulosa-Cat, 2023-11-05:
after using `sudo rpi-update` update to `Linux Pi-Server 6.1.61-v8+ #1696 SMP PREEMPT Thu Nov  2 16:44:46 GMT 2023 aarch64`
still got `time_pps_fetch() error -1 (Connection timed out)`
maybe only `sudo rpi-update pulls/5478` will work?

Nebulosa-Cat, 2023-11-05:
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
and looks `sudo rpi-update pulls/5478` not work

romm32, 2024-01-29:
Hello. I am running the Raspberry OS, I downloaded the current version (2023-12, 32-bit version) and then ran raspi-update. I am now running an updated version from Jan 22 of 2024. I followed all the instructions with a fresh install of the OS (before starting to run the suggested commands, I ran an apt update then apt upgrade), until I got the connection timeout error in the ppstest. I added the arm64bit line to /boot/config.txt, then rebooted, and nothing happened. I also tried with the raspi-update (as previously mentioned), and a reboot, and it is still not working. I am quite new to Raspberry Pis and don't know if there is something I am doing wrong, or if the issue is a bug in the OS, but I would appreciate any help available.
Thanks in advance

domschl, 2024-01-30:
@romm32 : Non of the fixes should be necessary anymore. Which model of Raspberry Pi are you using?
Please paste the `ppstest` command together with it's output into the bug-report.
E.g. for me it looks like:

```
sudo ppstest /dev/pps0
trying PPS source "/dev/pps0"
found PPS source "/dev/pps0"
ok, found 1 source(s), now start fetching data...
source 0 - assert 1706619523.000001477, sequence: 1233465 - clear  0.000000000, sequence: 0
source 0 - assert 1706619524.000001080, sequence: 1233466 - clear  0.000000000, sequence: 0
```

I should update the instructions once we figure out what happened with your installation.

domschl, 2024-01-30:
I just checked: there is _still_ ongoing work on this bug here [Raspberry kernel pps issue 5430](https://github.com/raspberrypi/linux/issues/5430) .
One thing (if you have one of the newer models) you can try is to use Raspberry OS 64bit?

romm32, 2024-01-30:
I am using a Raspberry 4 Model B. I was first using it with Ubuntu 22, then switched to Raspberry OS and tried both for 32bit then for 64bit (versions from December 2023, following what was mentioned here). I tried the arm64bit change and it didn't work, nor did a raspi-update. The output was similar to yours, except I was getting the following line right after the "ok, found 1 source(s)...".

`time_pps_fetch() error -1 (Connection timed out)`

Given I am following this guide for my undergraduate final project, and this was one of many things left on my to-do list, I kept trying with different settings yesterday. I eventually switched to Raspberry OS for 64bit, an archive version from September 2022, and everything worked just fine (no need to try any fixes). I know it is not exactly a solution, but I guess this should be enough for the project I am working on. I was able to get chrony working, but I don't see the PPS as one of the sources. My GPS antenna is kind of bad, and I was working indoors, so I am planning on testing everything when I have a decent amount of GPS satellites available (about 10), and hopefully I will see the PPS as one of the sources.

Thank you for your quick answer, I will continue following these issues just in case someone finds another fix I could try in the future.

aGGreSSiv, 2024-02-27:
Hello,
It's an interesting problem. The NTP server is currently installed in 3 different models, pi3, pi4 and pi5. Pi4 and pi5 have the same operating system. The versions are the same. both are 64bit. (I'm not sure if it is independent of the operating system, the kernal versions are the same) However, while pi3 and pi4 work without any problems, I am experiencing this problem on pi5. I tried every suggestion I found here and online. none of them helped. As I mentioned in my previous questions, I am not very good at Linux. If everything is the same, what's left? If you find a solution or see an update released that will solve this problem, can you write it here?

Nebulosa-Cat, 2024-03-06:
after I'm fully manuly upgrade to PiOS lite Bookworm (follow this guide: https://gist.github.com/jauderho/6b7d42030e264a135450ecc0ba521bd8)

and i delete the `bcm2708.pps_gpio_pin=4` at `/boot/firmware/cmdline.txt`
(the cmdline.txt and config.txt looks move to /boot/firmware at bookworm)

now it work normally

domschl, 2024-03-06:
Thank you @Nebulosa-Cat for this information! I will update the guide.

aGGreSSiv, 2024-03-06:
it shouldn`t be this hard. @Nebulosa-Cat , i thing ill wait for to get fixed with routine updates..

ZogKarndon, 2024-04-08:
I'm having the same trouble.   I have a RPi 3b with the Adafruit Ultimate GPS Hat, running Raspberry Pi OS Lite (32 bit, release 2024-03-15) - Bookworm release

My  /boot/firmware/config.txt changes are:
```
dtoverlay=pi3-disable-bt
dtoverlay=pps-gpio,gpiopin=4
enable_uart=1
init_uart_baud=9600
arm_64bit=0
```
Still, `sudo ppstest /dev/pps0` results in:
```
trying PPS source "/dev/pps0"
found PPS source "/dev/pps0"
ok, found 1 source(s), now start fetching data...
time_pps_fetch() error -1 (Connection timed out)
time_pps_fetch() error -1 (Connection timed out)
time_pps_fetch() error -1 (Connection timed out)
time_pps_fetch() error -1 (Connection timed out)
```
Clearly I'm doing *something* wrong, but I don't know what.

Nebulosa-Cat, 2024-04-09:
@ZogKarndon
some of my `/boot/fireware/config.txt`:
```
[all]
auto_initramfs=1
enable_uart=1
dtoverlay=pps-gpio,gpiopin=4
hdmi_enable_4kp60=1
```

and my `/boot/fireware/cmdline.txt`:
```
console=tty1 root=PARTUUID=50cc6c23-02 rootfstype=ext4 fsck.repair=yes rootwait  cgroup_enable=memory cgroup_memory=1
```

and if you not get 3D-Lock yet you will recive `time_pps_fetch() error -1 (Connection timed out) ` too, might be check `cgps`

domschl, 2024-04-09:
Some additional checkpoints:

Are you loading both required kernel modules (e.g. in `/etc/modules-load.d/raspberrypi.conf`):

```
pps-gpio
pps-ldisc
```

Please try:

```bash
 sudo dmesg | grep pps
```

We can then compare the behavior of the kernel modules with this:
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
domschl, 2024-06-07:
Just to make sure:

You know that in addition to the USB connection, you need to soldier a cable to Adafruit's PPS output pin and connect that to Raspberry GPIO Pin 4?

(Sorry, I just want to make sure that connection is ok)

Reinitialized, 2024-08-28:
So I am not quite sure what happened, debugging this has left me quite tired, but after scouring through various issues on the matter, I found the following command over at https://github.com/raspberrypi/linux/issues/5430 which seems to have kicked the pps signal into gear:
`while true; do gpioset gpiochip0 17=1; gpioset gpiochip0 17=0; sleep 1; done & ppstest /dev/pps0`

I'll try to do some additional digging into exactly what made this work, but throwing it here in case it can save others some much frustrating debugging time on the matter.

owensresearch, 2025-01-03:
Is this still an issue for anyone? I am running a Raspberry Pi 3B+ with the Adafruit Ultimate GPS v3 Serial module. 64-bit OS.

I have tried the fudged PPS trick by putting GPIO 17 & 18 together and running a loop. This works for me.. actually gives me a PPS reading on gpsmon.

I have a 3D DGPS fix.
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

During intial setup/testing i was using a random old cable i had laying around and didn't realize that 2 of the pins were actually connected. So, this resulted in 5V going towards the PPS pin for about 1 hour. Could this have fried my PPS function on the Adafruit? I put a multimeter on the pin and can see 0.01V going up and down by .01 ish about every second. Assume the multimeter can't read the voltage fluctuations fast enough. Tried switching to mA and i can see spikes every second. Seems like i have a pulse.. just not sure if strong enough.

I'm no expert here.. i'm a network guy. Does this sound like my Adafruit module is fried or is this some software issue?

owensresearch, 2025-01-03:
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

Any luck? I'm about at the same place as you. Different model Pi.

Have you put any kind of multimeter on the Adafruit PPS pin? I did and it seems like i can't read the 3.3V fast enough.. but i do see a pulse of some sort with mA mode.

Would be curious to hear any progress you made.

TheSubWayKing, 2025-01-16:
Same issue with a Raspberry Pi 3 Model B+. GPS fix achieved in gpsmon and cgps, everything looks as expected other than gpsmon shows "PPS = N/A". Antenna has clear view of the sky.

sudo ppscheck /dev/pps0

returns:

 "PPS ioctl(TIOCMIWAIT) failed: 25 Inappropriate ioctl for device"

sudo ppstest /dev/pps0

returns :

"found PPS source "/dev/pps1"
ok, found 1 source(s), now start fetching data...
time_pps_fetch() error -1 (Connection timed out)"

I've had my oscope on the PPS pin and have confirmed valid PPS signal with High of 3.3v for 0.1 seconds at 1 second intervals.

I'm using a u-blox M8Q breakout module and have confirmed configuration of PPS output using the ubxtool, as measured by the oscope.

Can someone please offer some insight/resolution? Thanks

SushiFanta, 2025-01-17:
Same problem. I have not moved on to the chrony part of the guide yet.
Raspberry Pi 5, Bookworm 64-bit, Waveshare Max-M8Q GNSS hat via serial.

It looks like the config file has moved from /etc/modules-load.d/raspberrypi.conf to /etc/modules-load.d/modules.conf, so I added them there and they seem to be loading.

dmesg | grep pps
[    0.027943] pps_core: LinuxPPS API ver. 1 registered
[    0.027944] pps_core: Software ver. 5.3.6 - Copyright 2005-2007 Rodolfo Giometti <giometti@linux.it>
[    2.120182] pps pps0: new PPS source pps@4.-1
[    2.120200] pps pps0: Registered IRQ 163 as PPS source
[    2.127870] pps_ldisc: PPS line discipline registered
[    4.466885] pps pps1: new PPS source ptp0
[    7.972511] pps pps2: new PPS source ttyAMA0
[    7.972526] pps pps2: source "/dev/ttyAMA0" added

sudo ppstest /dev/pps0
trying PPS source "/dev/pps0"
found PPS source "/dev/pps0"
ok, found 1 source(s), now start fetching data...
time_pps_fetch() error -1 (Connection timed out)

cgps indicates a 3D Fix with 4 satellites and lists the time, but GPSmon shaws PPS: N/A and does not list a time. gpsd doesn't work.
gpsd:ERROR: can't run with neither control socket nor devices

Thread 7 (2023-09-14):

Improvement suggestions

Lefuneste83, 2023-09-14:
Hello

Thank you for your help in setting up this nice solution.

I have implemented most of your code for the LCD output of the chronyc status, and everything works as expected. I have a few remarks.

-In latest Linux distributions, in particular on Debian 12, you cannot "pip install" a package system wide anymore in standard.
You must restrict the installation of python packages to a venv. The proposed way to circumvent this is to use pipx to install packages system wise, but pipx only accepts programs pacakges, not libraries (which is the case for gpsd-py3 and smbus).
So the only possible solution is to manually delete the file "EXTERNALLY-MANAGED" located in /usr/lib/python3.xx/.
Considering that this venv constraint will be more and more widespread as systems get updated, you should consider updating your installation documentation.

-Considering the display itself, I believe it would be useful to replace some static information which takes some room, or to switch the content  of a line every once in a while, in particular for one missing very important information, which is the STRATUM status of the server.
If you have a synchronization issue of any kind (like a process unable to access SHM) your server can be degraded to a higher stratum level without any notice. It will still serve time internally on your LAN, but as a lower grade reference. So I believe it would be nice to have the current stratum level directly displayed as well.

I have fiddled with the code that would allow this, but haven't been successful in doing so. It would be nice to complete this ntp_offset() function to parse the stratum level as it processes the chronyc tracking output.
You could then alternate the second line of the display every 5 seconds or so with NTP: X.XXXXXXXXXsec / Stratum level : X
Or any other useful info such as RMS offset and Frequency, both of which have a slow evolution and have some level of importance.
Sorry I am not good enough in Python to work this out myself and also it would be valuable for the community.

Thanks!

Snipet of the current function below

```
def ntp_offset():
    cmd = ["chronyc", "tracking"]
    ret = exec_cmd(cmd)
    for line in ret:
        pars = line.split(":", 1)
        if len(pars) == 2:
            if pars[0].strip() == "System time":
                sub_pars = pars[1].strip().split(" ")
                if len(sub_pars) > 2:
                    val = float(sub_pars[0])
                    if "slow" == sub_pars[2]:
                        val = -1.0 * val
            return "NTP: {:+12.9f}sec".format(val)
```

Lefuneste83, 2023-09-14:
Ok forget it, I asked my new best friend Chat GPT. It took about half a second to generate the following code which I only very slightly modified to adjust the display...
I guess coders will start to get worried...

```
def ntp_offset():
    cmd = ["chronyc", "tracking"]
    ret = exec_cmd(cmd)
    ntp_val = None
    stratum_val = None
    for line in ret:
        pars = line.split(":", 1)
        if len(pars) == 2:
            key = pars[0].strip()
            value = pars[1].strip()
            if key == "System time":
                sub_pars = value.split(" ")
                if len(sub_pars) > 2:
                    ntp_val = float(sub_pars[0])
                    if "slow" == sub_pars[2]:
                        ntp_val = -1.0 * ntp_val
            elif key == "Stratum":
                stratum_val = int(value)

    if ntp_val is not None and stratum_val is not None:
        return "S:{} NTP:{:+12.9f}s".format(stratum_val, ntp_val)
    elif ntp_val is not None:
        return "NTP: {:+12.9f}sec".format(ntp_val)
    else:
        return "NTP and Stratum values not found"
```

domschl, 2023-09-15:
Thank you for the suggestions and remarks. I will look into both.

- Having stratum information available is definitely a good idea.
- Yes python packages became more of an effort. My bad recommendation would be to use `pip` with the infamous `--break-system-packages` flag for `gpsd-py3` since it has no dependencies. `venv` is of course the correct solution, this would require to modify the `chronotron.service` file to point to the specific python instance of the `venv`, which requires some documentation effort. I guess that's the way to go.

I'll update this, once I've had time to look at this.

aGGreSSiv, 2023-11-15:
Hello,

I wanted to install the screen by following the instructions, but I could not succeed in the installation due to the errors mentioned above, which I still had difficulty understanding (I am not a programmer). Have you had a chance to update the instructions to use screen?

Everything is working now, but I have to check by ssh. It would be nice to see from the screen if everything is OK.

domschl, 2023-12-21:
@aGGreSSiv : I've updated the documentation of the install process. If you are still having trouble, please open a new issue and describe at what step you're stuck, and we have a look at it!

aGGreSSiv, 2023-12-21:
> @aGGreSSiv : I've updated the documentation of the install process. If you are still having trouble, please open a new issue and describe at what step you're stuck, and we have a look at it!

Thank you very much. I will try it as soon as possible.

aGGreSSiv, 2023-12-21:
> @aGGreSSiv : I've updated the documentation of the install process. If you are still having trouble, please open a new issue and describe at what step you're stuck, and we have a look at it!

I connected remotely and followed the steps one by one according to the instructions. First I updated the operating system, then I entered the commands one by one. None of the commands gave an error. The LCD is not plugged in right now, maybe that's why it gives an error, but when I check the chronotron service status to check, it gives the following output.

```
pi@raspberrypi:~ $ sudo systemctl status chronotron
● chronotron.service - Display chrony statistics on 4x20 LCD
     Loaded: loaded (/etc/systemd/system/chronotron.service; enabled; vendor preset: enabled)
     Active: failed (Result: exit-code) since Thu 2023-12-21 13:22:11 +03; 11s ago
    Process: 537 ExecStart=/opt/chronotron/bin/python /opt/chronotron/chronotron.py (code=exited, status=1/FAILURE)
   Main PID: 537 (code=exited, status=1/FAILURE)
        CPU: 422ms

Dec 21 13:22:11 raspberrypi python[537]: Traceback (most recent call last):
Dec 21 13:22:11 raspberrypi python[537]:   File "/opt/chronotron/chronotron.py", line 237, in <module>
Dec 21 13:22:11 raspberrypi python[537]:     main_loop()
Dec 21 13:22:11 raspberrypi python[537]:   File "/opt/chronotron/chronotron.py", line 151, in main_loop
Dec 21 13:22:11 raspberrypi python[537]:     lcd = LcdDisplay()
Dec 21 13:22:11 raspberrypi python[537]:   File "/opt/chronotron/i2c_lcd.py", line 8, in __init__
Dec 21 13:22:11 raspberrypi python[537]:     self.bus = smbus.SMBus(sm_bus)  # Rev 1 Pi: 0, Rev 2 Pi: 1
Dec 21 13:22:11 raspberrypi python[537]: FileNotFoundError: [Errno 2] No such file or directory
Dec 21 13:22:11 raspberrypi systemd[1]: chronotron.service: Main process exited, code=exited, status=1/FAILURE
Dec 21 13:22:11 raspberrypi systemd[1]: chronotron.service: Failed with result 'exit-code'.

```
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

Closed 2023-12-21.

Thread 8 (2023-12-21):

LCD screen installation problem

aGGreSSiv, 2023-12-21:
> @aGGreSSiv : I've updated the documentation of the install process. If you are still having trouble, please open a new issue and describe at what step you're stuck, and we have a look at it!

I connected remotely and followed the steps one by one according to the instructions. First I updated the operating system, then I entered the commands one by one. None of the commands gave an error. The LCD is not plugged in right now, maybe that's why it gives an error, but when I check the chronotron service status to check, it gives the following output.

```
pi@raspberrypi:~ $ sudo systemctl status chronotron
● chronotron.service - Display chrony statistics on 4x20 LCD
     Loaded: loaded (/etc/systemd/system/chronotron.service; enabled; vendor preset: enabled)
     Active: failed (Result: exit-code) since Thu 2023-12-21 13:22:11 +03; 11s ago
    Process: 537 ExecStart=/opt/chronotron/bin/python /opt/chronotron/chronotron.py (code=exited, status=1/FAILURE)
   Main PID: 537 (code=exited, status=1/FAILURE)
        CPU: 422ms

Dec 21 13:22:11 raspberrypi python[537]: Traceback (most recent call last):
Dec 21 13:22:11 raspberrypi python[537]:   File "/opt/chronotron/chronotron.py", line 237, in <module>
Dec 21 13:22:11 raspberrypi python[537]:     main_loop()
Dec 21 13:22:11 raspberrypi python[537]:   File "/opt/chronotron/chronotron.py", line 151, in main_loop
Dec 21 13:22:11 raspberrypi python[537]:     lcd = LcdDisplay()
Dec 21 13:22:11 raspberrypi python[537]:   File "/opt/chronotron/i2c_lcd.py", line 8, in __init__
Dec 21 13:22:11 raspberrypi python[537]:     self.bus = smbus.SMBus(sm_bus)  # Rev 1 Pi: 0, Rev 2 Pi: 1
Dec 21 13:22:11 raspberrypi python[537]: FileNotFoundError: [Errno 2] No such file or directory
Dec 21 13:22:11 raspberrypi systemd[1]: chronotron.service: Main process exited, code=exited, status=1/FAILURE
Dec 21 13:22:11 raspberrypi systemd[1]: chronotron.service: Failed with result 'exit-code'.

```
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

domschl, 2023-12-21:
You need to install `smbus` within the python virtual environment:

```bash
cd /opt/chronotron
source bin/activate
pip install smbus
```

then restart the chronotron service.

domschl, 2023-12-21:
Also, make sure that I2C is active: `sudo raspi-config`, select "Interface options", and make sure that I2C is enabled.

You can verify with: `i2cdetect 1`

It should show something like:

```
WARNING! This program can confuse your I2C bus, cause data loss and worse!
I will probe file /dev/i2c-1.
I will probe address range 0x08-0x77.
Continue? [Y/n]
     0  1  2  3  4  5  6  7  8  9  a  b  c  d  e  f
00:                         -- -- -- -- -- -- -- --
10: -- -- -- -- -- -- -- -- -- -- -- -- -- -- -- --
20: -- -- -- -- -- -- -- 27 -- -- -- -- -- -- -- --
30: -- -- -- -- -- -- -- -- -- -- -- -- -- -- -- --
40: -- -- -- -- -- -- -- -- -- -- -- -- -- -- -- --
50: -- -- -- -- -- -- -- -- -- -- -- -- -- -- -- --
60: -- -- -- -- -- -- -- -- -- -- -- -- -- -- -- --
70: -- -- -- -- -- -- -- --
```

That `27` should appear, if your display is connected correctly!

aGGreSSiv, 2023-12-21:
I2c Activated

```
pi@raspberrypi:~ $ i2cdetect 1
WARNING! This program can confuse your I2C bus, cause data loss and worse!
I will probe file /dev/i2c-1.
I will probe address range 0x08-0x77.
Continue? [Y/n] y
     0  1  2  3  4  5  6  7  8  9  a  b  c  d  e  f
00:                         -- -- -- -- -- -- -- --
10: -- -- -- -- -- -- -- -- -- -- -- -- -- -- -- --
20: -- -- -- -- -- -- -- -- -- -- -- -- -- -- -- --
30: -- -- -- -- -- -- -- -- -- -- -- -- -- -- -- --
40: -- -- -- -- -- -- -- -- -- -- -- -- -- -- -- --
50: -- -- -- -- -- -- -- -- -- -- -- -- -- -- -- --
60: -- -- -- -- -- -- -- -- -- -- -- -- -- -- -- --
70: -- -- -- -- -- -- -- --

```
smbus İnstalled;
```
(chronotron) pi@raspberrypi:/opt/chronotron $ sudo pip install smbus
Looking in indexes: https://pypi.org/simple, https://www.piwheels.org/simple
Collecting smbus
  Downloading smbus-1.1.post2.tar.gz (104 kB)
     |████████████████████████████████| 104 kB 1.1 MB/s
Building wheels for collected packages: smbus
  Building wheel for smbus (setup.py) ... done
  Created wheel for smbus: filename=smbus-1.1.post2-cp39-cp39-linux_aarch64.whl size=40622 sha256=9634b265a325d0c514b1a243e0f9d3c8df653fb0ea80daabe45f60db23716c34
  Stored in directory: /root/.cache/pip/wheels/27/6b/5f/d61caec49a6f3347a083b3e43fa397c353e086e081029f174d
Successfully built smbus
Installing collected packages: smbus
Successfully installed smbus-1.1.post2

```

but the result did not change;
```
pi@raspberrypi:~ $ sudo systemctl status chronotron
● chronotron.service - Display chrony statistics on 4x20 LCD
     Loaded: loaded (/etc/systemd/system/chronotron.service; enabled; vendor preset: enabled)
     Active: failed (Result: exit-code) since Thu 2023-12-21 15:21:16 +03; 51s ago
    Process: 491 ExecStart=/opt/chronotron/bin/python /opt/chronotron/chronotron.py (code=exited, status=1/FAILURE)
   Main PID: 491 (code=exited, status=1/FAILURE)
        CPU: 445ms

Dec 21 15:21:16 raspberrypi python[491]:     main_loop()
Dec 21 15:21:16 raspberrypi python[491]:   File "/opt/chronotron/chronotron.py", line 151, in main_loop
Dec 21 15:21:16 raspberrypi python[491]:     lcd = LcdDisplay()
Dec 21 15:21:16 raspberrypi python[491]:   File "/opt/chronotron/i2c_lcd.py", line 21, in __init__
Dec 21 15:21:16 raspberrypi python[491]:     self.write(0x33, self.type_command)  # init sequence: 0x03, 0x03
Dec 21 15:21:16 raspberrypi python[491]:   File "/opt/chronotron/i2c_lcd.py", line 45, in write
Dec 21 15:21:16 raspberrypi python[491]:     self.bus.write_byte(self.i2c_addr, hi_byte)
Dec 21 15:21:16 raspberrypi python[491]: OSError: [Errno 5] Input/output error
Dec 21 15:21:16 raspberrypi systemd[1]: chronotron.service: Main process exited, code=exited, status=1/FAILURE
Dec 21 15:21:16 raspberrypi systemd[1]: chronotron.service: Failed with result 'exit-code'.

```

Could the problem be related to the LCD Screen not being installed yet? I'll connect it when I get home this evening.

domschl, 2023-12-21:
The HD44780 display is not visible on the I2C bus. The possible causes are:

- electric connection not working (four cables need to be correctly connected)
- You have a Raspberry Pi Gen 1 (the very old first model)? (verify with `i2cdetect 0` if the other bus is used.)

`i2cdetect 1` should detect the `27` as active, if the display is correctly connected. This is completely independent of any Chronotron software.

As for the display driver: it's implemented in python in "i2c_lcd.py", so no extra software is needed.

aGGreSSiv, 2023-12-21:
Ok. I'll plug in the screen and try it tonight. As I said, I installed apps by accessing the Pi remotely. I will share the result.

domschl, 2023-12-21:
Sorry I missed that!

I've updated the code to give proper diagnostics for missing displays. It would now log:

```
Dec 21 14:37:30 chronotron systemd[1]: Started chronotron.service - Display chrony statistics on 4x20 LCD.
Dec 21 14:37:30 chronotron python[39157]: INFO:Chronotron:Chronotron version 2.0.0 starting
Dec 21 14:37:30 chronotron python[39157]: ERROR:LcdDisplay:Cannot open LCD on I2C bus: [Errno 2] No such file or directory
Dec 21 14:37:30 chronotron python[39157]: ERROR:Chronotron:Failed to open display, exiting...
Dec 21 14:37:30 chronotron systemd[1]: chronotron.service: Main process exited, code=exited, status=255/EXCEPTION
Dec 21 14:37:30 chronotron systemd[1]: chronotron.service: Failed with result 'exit-code'.
```

aGGreSSiv, 2023-12-21:
Yes, LCD is visible now
```
pi@raspberrypi:~ $ sudo i2cdetect 1
WARNING! This program can confuse your I2C bus, cause data loss and worse!
I will probe file /dev/i2c-1.
I will probe address range 0x08-0x77.
Continue? [Y/n] y
     0  1  2  3  4  5  6  7  8  9  a  b  c  d  e  f
00:                         -- -- -- -- -- -- -- --
10: -- -- -- -- -- -- -- -- -- -- -- -- -- -- -- --
20: -- -- -- -- -- -- -- 27 -- -- -- -- -- -- -- --
30: -- -- -- -- -- -- -- -- -- -- -- -- -- -- -- --
40: -- -- -- -- -- -- -- -- -- -- -- -- -- -- -- --
50: -- -- -- -- -- -- -- -- -- -- -- -- -- -- -- --
60: -- -- -- -- -- -- -- -- -- -- -- -- -- -- -- --
70: -- -- -- -- -- -- -- --

```
chronotron service also works properly;
```
pi@raspberrypi:~ $ sudo systemctl status chronotron
● chronotron.service - Display chrony statistics on 4x20 LCD
     Loaded: loaded (/etc/systemd/system/chronotron.service; enabled; vendor preset: enabled)
     Active: active (running) since Thu 2023-12-21 19:19:56 +03; 1min 47s ago
   Main PID: 507 (python)
      Tasks: 1 (limit: 779)
        CPU: 7.686s
     CGroup: /system.slice/chronotron.service
             └─507 /opt/chronotron/bin/python /opt/chronotron/chronotron.py

Dec 21 19:19:56 raspberrypi systemd[1]: Started Display chrony statistics on 4x20 LCD.
Dec 21 19:19:59 raspberrypi python[507]: INFO:Chronotron:Chronotron version 2.0.0 starting
Dec 21 19:20:00 raspberrypi python[507]: INFO:Chronotron:Chrony stratum level changed to 1
Dec 21 19:20:43 raspberrypi python[507]: INFO:Chronotron:Chrony aquired lock to time source
Dec 21 19:20:43 raspberrypi python[507]: INFO:Chronotron:Chrony receiving time source from time.ume.tubitak.g>
Dec 21 19:20:43 raspberrypi python[507]: INFO:Chronotron:Chrony stratum level changed to 2
Dec 21 19:21:26 raspberrypi python[507]: INFO:Chronotron:Chrony receiving time source from PPS
Dec 21 19:21:26 raspberrypi python[507]: INFO:Chronotron:Chrony locked to high precision GPS PPS signal
Dec 21 19:21:27 raspberrypi python[507]: INFO:Chronotron:Chrony stratum level changed to 1
```
But I don't see anything except the backlight of the screen is on. Since I see the I2C address, there is no problem with the connection.

I did the installation via [this site ](https://blog.networkprofile.org/gps-backed-local-ntp-server/)before seeing your post. But later, when I wanted to add a screen and looked at your NTP server instructions, I saw that they were identical. However, the reason why there is no image on the screen may be something I missed.

Since I'm not a software developer and I don't know much about Linux, I might be wasting your time with something stupid.

aGGreSSiv, 2023-12-21:
Yes, I forgot to do the stupid little thing. It came to mind as soon as I pressed enter after my last post. There was a small potentiometer behind these screens, right? :)

Thanks for your help, everything is working as it should now.

domschl, 2023-12-21:
Excellent. I close this then.

Closed 2023-12-21.

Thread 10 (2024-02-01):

Adafruit modules (ie MTK3339 ) a poor choice for timing because of the PPS to NMEA offset

basrijn, 2024-02-01:
Hi,

I'm fairly certain the Adafruit modules (or any Mediatek MTK3339 based modules) are a poor choice for clock applications. The timing of the NMEA output relative to the PPS signal is very unfortunate as it hovers around 500ms. Since it moves around the 500ms mark the applications have trouble determining what second to round to. You might up with a time that has very high accuracy for the rollover to the next second (since PPS drives that), but end up being off by a full second from the correct time.

You can see this issue in your examples with the 512ms offset reported my chrony sources.

To show it's actual effect on the time on your system, run:
`watch -n 1 date +"%T.%3N"`

I've found some other reports on this issue. Somebody mentioned this being a navigation GPS chip vs a chip that is designed with timing in mind. Timing chips place the NMEA string at a specific offset to the PPS and prefer high in the sky satellites to reduce multipathing.

To take any Linux OS issues out of the mix, I tested this on a microcontroller with a very basic test program to show PPS timing vs NMEA timing, and it confirms the consistent ~ 500ms offset. Interestingly it seems to always be around 500ms, it's not different for every boot

domschl, 2024-02-02:
An offset of several hundred milliseconds between PPS signal and serial time is to be expected and not necessarily a problem. Did you follow the instructions at: [Synchronizing the offset between serial time information and PPS](https://github.com/domschl/RaspberryNtpServer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) in order to compensate for that offset?

basrijn, 2024-02-08:
I'll do some more testing, but I'm pretty sure I had the offset configured correctly and did not see chrony doing what you described. NTP was much closer to the PPS (32ms or so), so that should work.
When you say "nudge" the offset, do you mean the setting in the config file?

domschl, 2024-02-08:
'nudge': sorry, yes the offset setting in:

`refclock SHM 0 refid GPS precision 1e-1 offset 0.512 delay 0.2 noselect`

512 ms (= `0.512`) in this example.

I had checked quite a number of different GPS chips, and the only difference that mattered in real life was reception: some chips support multiple GPS systems and thus can receive more satellites. Making sure that reception is good (free view of sky) has (in my experience) much larger impact on time signal quality than chip set optimizations.

There are also variants of GPS chip sets specifically suited for precision time applications (eg NEO-M8T), but it didn't improve the precision for networked clients: the error introduced by network time synchronization always outweighed those optimizations. So optimizing the hardware like that only provides (possibly) an advantage on the time server host itself. You should get good results with any GPS chipset (even the cheapest).

basrijn, 2024-02-09:
I just redid the full config. Tweaked the offset (0.480) as per the instructions. I don't know if the `watch -n 1 date +"%T.%3N"` is a good test, but it jumps seconds as before. Comparing against an phone running a millisecond clock. It's also significantly off

chronyc sources shows:

#? GPS                           0   4   377    21    +24ms[  +24ms] +/-  200ms
#* PPS1                          0   4   377    22  +4042ns[  +14us] +/-  329ns
^- s173-183-146-26.ab.hsia.>     2   8   377   102  -4801us[-4772us] +/-   41ms
^- ntp.mtl2.ca.leaseweb.net      2   8   377   159  -6685us[-6659us] +/-  169ms
^- ntp3.torix.ca                 1   8   377    95  -3325us[-3297us] +/-   30ms
^- muug.ca                       2   8   377    97    -12ms[  -12ms] +/-   80ms

Not sure if 'date' pulls time from a local clock that is not synchronized often (rtcsync, every 11 min?). I installed ntpdate and running ` watch -n 1 ntpdate -q localhost` show the exact same behavior.

domschl, 2024-02-09:
So your installation seems to work just fine (you gave PPS lock with deviation < 1uS).

`watch` is not a good way to determine the precision of the time signal, it just samples the date-output.

Use `chronyc tracking` instead, this with give actual meaningful statistics on the precision of your clock, sample output:

```
Reference ID    : 50505330 (PPS0)
Stratum         : 1
Ref time (UTC)  : Fri Feb 09 15:00:40 2024
System time     : 0.000000100 seconds slow of NTP time
Last offset     : -0.000000230 seconds
RMS offset      : 0.000000804 seconds
Frequency       : 2.324 ppm slow
Residual freq   : -0.000 ppm
Skew            : 0.020 ppm
Root delay      : 0.000000001 seconds
Root dispersion : 0.000016292 seconds
Update interval : 16.0 seconds
Leap status     : Normal
```

The meaning of the fields is explained [here](https://chrony-project.org/doc/4.4/chronyc.html).

basrijn, 2024-02-09:
Hi

Would ntpdate be an ok test? I think that queries the NTP server directly?

domschl, 2024-02-10:
`ntpdate` is a retired tool to set NTP time on a client by querying an NTP once, it is no longer used. It has been replace by ntp (or now chrony) servers on client side too.

What exactly do you want to test?

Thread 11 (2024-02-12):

CM4 and Timebeat LEA-M8F Baseboard

p47-6, 2024-02-12:
Hi,
i've tried to follow the setup as close as possible with a CM4 but i wanted to use the SYNC_IN pin on the CM4 breakout port since i've got a LEA-M8F Board from Timebeat (https://store.timebeat.app/products/gnss-raspberry-pi-cm4-module?variant=42280855699627).

My problem is that i still get timeouts with `ppstest `on pps0 and i cannot figure out why:
```
$ sudo ppstest /dev/pps0
trying PPS source "/dev/pps0"
found PPS source "/dev/pps0"
ok, found 1 source(s), now start fetching data...
time_pps_fetch() error -1 (Connection timed out)
time_pps_fetch() error -1 (Connection timed out)
time_pps_fetch() error -1 (Connection timed out)
time_pps_fetch() error -1 (Connection timed out)
```

With test ptp i do not get a problem:

```
$ sudo ./testptp -d /dev/ptp0 -L 0,1
set pin function okay
$ sudo  ./testptp -d /dev/ptp0 -e 5
external time stamp request okay
event index 0 at 9036.169914149
event index 0 at 9037.169893564
event index 0 at 9038.169871992
event index 0 at 9039.169849439
event index 0 at 9040.169825905
```

also if i hook up a logic analyzer on the physical pin i get a clean 1pps signal as soon as the GPS locks.

here some extra info:
```
$ uname -a
Linux cm4 6.6.16-v8+ #1728 SMP PREEMPT Tue Feb  6 17:21:42 GMT 2024 aarch64 GNU/Linux
```
```
$ lsb_release -a
No LSB modules are available.
Distributor ID: Debian
Description:    Debian GNU/Linux 12 (bookworm)
Release:        12
Codename:       bookworm
```
```
$ sudo chronyc
chrony version 4.3
Copyright (C) 1997-2003, 2007, 2009-2022 Richard P. Curnow and others
chrony comes with ABSOLUTELY NO WARRANTY.  This is free software, and
you are welcome to redistribute it under certain conditions.  See the
GNU General Public License version 2 for details.

chronyc> sourcestats
Name/IP Address            NP  NR  Span  Frequency  Freq Skew  Offset  Std Dev
==============================================================================
PPS0                        0   0     0     +0.000   2000.000     +0ns  4000ms
GPS                         7   4    97   +128.275    353.883   +646ms  4399us
185.13.148.71               7   5   25m     +0.141      1.468  -1105us   258us
vif1201.leaf2.network.pr>   6   3   773     -0.500      1.174   +264us    85us
nono.com                    7   4   453     -0.311      0.473   -479us    29us
ntp1.aew1.soe.as49436.net   6   3   21m     +0.339      3.956   +332us   423us
172.28.100.10              11   9   644     -0.188      0.097   +376us    14us
chronyc> sources
MS Name/IP address         Stratum Poll Reach LastRx Last sample
===============================================================================
#? PPS0                          0   4     0     -     +0ns[   +0ns] +/-    0ns
#? GPS                           0   4   377    23   +645ms[ +645ms] +/-  200ms
^+ 185.13.148.71                 2   8   377    90  -1429us[-1429us] +/-   12ms
^+ vif1201.leaf2.network.pr>     2   7   377    24   +332us[ +332us] +/-   16ms
^- nono.com                      2   6   377    24   -577us[ -577us] +/-   49ms
^* ntp1.aew1.soe.as49436.net     1   8   377    93   +297us[ +378us] +/-   11ms
^- 172.28.100.10                 3   6   377    30   +362us[ +362us] +/-   49ms
```

any suggestions ?

domschl, 2024-02-12:
Did you check `dmesg` for the `pps` [related messages](https://github.com/domschl/RaspberryNtpServer#setting-up-pps)?

How did you configure the raspberry pi kernel driver to use `sync-in`?

p47-6, 2024-02-13:
Here is the dmesg output:
```
[    0.083028] pps_core: LinuxPPS API ver. 1 registered
[    0.083048] pps_core: Software ver. 5.3.6 - Copyright 2005-2007 Rodolfo Giometti <giometti@linux.it>
[   10.107286] pps_ldisc: PPS line discipline registered
[   10.108043] pps pps0: new PPS source serial0
[   10.108078] pps pps0: source "/dev/ttyS0" added
```

I've acually did nothing special to configure it. It more or less had ptp0 out-of-the-box.
While i was researching the topic i've found https://github.com/jclark/rpi-cm4-ptp-guide but to be honest i did not realy understand whats going on. I've just used the testptp commands to doublecheck if something is working and tried to stick to your guide as close as possible.

domschl, 2024-02-13:
Both the rpi-cm-ptp-guide and that original product spec basically talk about PTP. I guess there is some missing information about the configuration of PPS kernel module: the PPS signal from the clock hardware has to be connected to some pin of Raspberry PI. For the hardware I tested with, one specifies this GPIO for the kernel modules with `bcm2708.pps_gpio_pin=4` and/or  `dtoverlay=pps-gpio,gpiopin=4` (GPIO 4 in this example). That results in a `dmesg` log output `new PPS source pps@4.-1` and `Registered IRQ 166 as PPS source` which shows that an interrupt driver is allocated by the kernel driver to handle the PPS signal.

I fear that the output you listed uses some (incomplete) defaults, and that there is something missing to configure your hardware. I didn't find any technical description on the company's web-site. Maybe you contact their support and ask how to configure the Raspberry kernel drivers for PPS (not just PTP) for their hardware?

We are missing something here.

domschl, 2024-02-13:
That documentation refers to pin 18:

dtoverlay=pps-gpio,gpiopin=18 (is that your hardware?)

<https://github.com/jclark/rpi-cm4-ptp-guide/blob/853f200106f40fcfa697ef4e94829931a5cf3dd5/os.md?plain=1#L42>

p47-6, 2024-02-13:
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

I've added
```
# Enable GPIO pin 18 for PPS (not always necessary, but useful for testing)
dtoverlay=pps-gpio,gpiopin=18
# realtime clock
dtoverlay=i2c-rtc,pcf85063a,i2c_csi_dsi
# fan
#dtoverlay=i2c-fan,emc2301,i2c_csi_dsi
# Make /dev/ttyAMA0 be connected to GPIO header pins 8 and 10
# This always disables Bluetooth
dtoverlay=disable-bt
```
to the config and now the dmesg output is the following:
```
$ dmesg |grep pps
[    0.089020] pps_core: LinuxPPS API ver. 1 registered
[    0.089040] pps_core: Software ver. 5.3.6 - Copyright 2005-2007 Rodolfo Giometti <giometti@linux.it>
[    7.552241] pps pps0: new PPS source pps@12.-1
[    7.552381] pps pps0: Registered IRQ 38 as PPS source
[   11.251002] pps_ldisc: PPS line discipline registered
[   11.252736] pps pps1: new PPS source serial0
[   11.252820] pps pps1: source "/dev/ttyS0" added
```

The problem is i get on pps0 and pps1 a timeout.

btw.: I totally mixed up ptp and pps in my head. I've also contacted the board vendor a while ago and they just referred to their docs.

domschl, 2024-02-13:
I finally found the documentation of your board on the manufacturers site.

From what I understood this board does _not_ support the PPS configuration used in this project. They seem to connect the PPS signal only to the network hardware of the CM4 (the PTP protocol uses specific ethernet hardware to transport the time signal via ethernet, and the CM4 has such a chip). That way the Raspberry PI Linux kernel doesn't have access to the 1PPS signal.

Unfortunately they do not seem to provide a mechanism to route the PPS signal from the M8N GPS chip to the Raspberry PI GPIOs.

Just to clarify again the differences between PTP and PPS linux protocols:

- PTP (your hardware uses specific ethernet-hardware-extensions to transmit the precision time signal over ethernet hardware. The CM4 module has this hardware and the Timebeat board send it's GPS time information to CM4 ethernet hardware using the ETH_SYNC hardware feather.
- This project uses PPS output of GPS modules connected to a Raspberry PI GPIO, and a kernel driver that uses the GPIO signal to synchronize chronyd.

PTP is basically a legacy protocol used in lab or telecom environments that uses specific hardware extensions to ethernet to transmit time signals. Every instance in the PTP network (switches, all network clients) need to support PTP for it to work.

If you do not have PTP network requirements (e.g. you are not in such a lab), then you could still follow the complete  [rpi-cm4-ptp-guide](https://github.com/jclark/rpi-cm4-ptp-guide/tree/main) instructions. This also sets up a `chronyd` time server that receives its time-sync information via PTP. You could then simply use that `chronyc` to sync time clients in your network completely ignoring the PTP stuff.

You would then not use any information of this project.

p47-6, 2024-02-14:
Thank you for the clarification.

Closed 2024-02-14.

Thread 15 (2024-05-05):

Chrony not responding to requests upon port forwarding

michaelschefczyk, 2024-05-05:
Thank you very much for providing this setup! I have been running two Raspberry Pi 4 NTP server for a long time. When upgrading to Raspberry Pi 5, I did switch to Chrony. This does provide stratum 1 time in a reliable manner.

The time server works well in my LAN and even across LANs via VPN.

What strikes me very odd is that I cannot get the Raspberry Pi 5 running the native Chrony version included with Debian Bookworm to respond externally, when forwarding port 123/UDP via my pfSense router.

Running ntpdate -q [IP of Raspberry Pi NTP server] does work without any issues in the LAN and via VPN. When forwarding 123/UDP from WAN to the Raspberry Pi NTP server, it does time out ("no server suitable for synchronization found"). When forwarding 123/UDP to the pfSsense router itself (localhost), which does get its time from the Raspberry Pi NTP server, everything is fine - except for stratum being 2 instead of 1. When forwarding the 123/UDP to the most trivial device within the LAN providing NTP (for example a homematic IP CCU3 - which has a Raspberry Pi 3 inside), everything does work (stratum 3). Thus, it does not seem to be a router/pfSense issue.

My chrony.conf does include allow and cmdallow (tried with and without "all").

Do others make the same observation? Are there any recommendations to cure this? Thanks a lot!

domschl, 2024-05-06:
What you've done looks good to me. My best guesses for looking why this doesn't work are:

- When you try from an external computer via pfsense, are you in a different IP network compared to your other trials? That would hint an `allow` problem. What did you configure for `allow`?
- Any issue with pfsense. Since pfsense (which I haven't used) seem to support it's own NTP-server, are you sure there isn't a conflict somewhere?

Other than that:

Maybe you just give in, and allow pfsense's NTP server to forward the client requests? While that gives you a stratum-2, one could debate, if forwarding via an application firewall actually keeps stratum-level at 1?

michaelschefczyk, 2024-05-12:
Thank you very much, again. I did find out that it is not a pfSenese-issue, but a chrony-issue.

The relevant setup in chrony.conf is:
allow
cmdallow 192.168/16

I did install good old ntp and then, the external access did work. What did not work then was the PPS-based clock - maybe because I did not adjust the offset in ntp. The strange thing was that after switching back to chrony, everything started working (stratum 1 clock & external access). The only thing I do dislike somewhat is that I did not find out why all of this did happen in the first place. I only know that two Pi5 computers in two different locations (but with the same setup) did perform alike.

Closed 2024-05-12.

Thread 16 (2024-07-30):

Anybody got this "gpsd[748]: gpsd:ERROR: accept: fail: Too many open files in system"  error before?

Nebulosa-Cat, 2024-07-30:
I have been encountering this error recently, and the log generated by this error has unexpectedly expanded my syslog and user.log to 10GB (almost filling up my SD card). Does anyone know how to solve this error?
```
2024-07-30T22:26:45.183731+08:00 NHI-RaspberryPi-4B gpsd[748]: gpsd:ERROR: accept: fail: Too many open files in system
2024-07-30T22:26:45.183779+08:00 NHI-RaspberryPi-4B gpsd[748]: gpsd:ERROR: accept: fail: Too many open files in system
2024-07-30T22:26:45.183825+08:00 NHI-RaspberryPi-4B gpsd[748]: gpsd:ERROR: accept: fail: Too many open files in system
2024-07-30T22:26:45.183867+08:00 NHI-RaspberryPi-4B gpsd[748]: gpsd:ERROR: accept: fail: Too many open files in system
2024-07-30T22:26:45.183915+08:00 NHI-RaspberryPi-4B gpsd[748]: gpsd:ERROR: accept: fail: Too many open files in system
2024-07-30T22:26:45.183960+08:00 NHI-RaspberryPi-4B gpsd[748]: gpsd:ERROR: accept: fail: Too many open files in system
2024-07-30T22:26:45.184002+08:00 NHI-RaspberryPi-4B gpsd[748]: gpsd:ERROR: accept: fail: Too many open files in system
2024-07-30T22:26:45.184050+08:00 NHI-RaspberryPi-4B gpsd[748]: gpsd:ERROR: accept: fail: Too many open files in system
2024-07-30T22:26:45.184093+08:00 NHI-RaspberryPi-4B gpsd[748]: gpsd:ERROR: accept: fail: Too many open files in system
2024-07-30T22:26:45.184141+08:00 NHI-RaspberryPi-4B gpsd[748]: gpsd:ERROR: accept: fail: Too many open files in system
```

and looks it create log super fast, this is my first time encountering this situation, is there anything I should check first?

domschl, 2024-07-31:
I couldn't find any hints about an existing problem with `gpsd` that would cause that.

My best guess would be: something else in your system exhausts file-handles.

One way to narrow things down would be to disable all other services and software you are running on the Raspberry, and check if the problem still exists?

Nebulosa-Cat, 2025-01-21:
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

I change my swap system to zram and this never happen again, and even I switch back to normal swap system it not happen too, maybe just the old swap have some problem make it randomly happen.

Closed 2025-01-21.

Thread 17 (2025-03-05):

Process: 1242 ExecStart=/opt/chronotron/chronotron.py (code=exited, status=1/FAILURE)

servebeer, 2025-03-05:
I just finished installing RaspberryNtpServer on a Raspberry PI 4. The s/w and GPS are working fine and chrony is synched and running. I just added a 4 line lcd display and ran through the setup in "Simple 4x20 LCD display for Raspberry Pi NTP Server". However, there is nothing being displayed and when I check the status of the service, I get this error:

jon@time:~/RaspberryNtpServer/src $ sudo systemctl status chronotron
x chronotron.service - Display chrony statistics on 4x20 LCD
     Loaded: loaded (/etc/systemd/system/chronotron.service; enabled; preset: enabled)
     Active: failed (Result: exit-code) since Wed 2025-03-05 07:43:12 CST; 8s ago
   Duration: 155ms
    Process: 1242 ExecStart=/opt/chronotron/chronotron.py (code=exited, status=1/FAILURE)
   Main PID: 1242 (code=exited, status=1/FAILURE)
        CPU: 156ms

Mar 05 07:43:12 time chronotron.py[1242]:     lcd = LcdDisplay(sm_bus=1, i2c_addr=0x27, cols=20, rows=4)
Mar 05 07:43:12 time chronotron.py[1242]:           ^^^^^^^^^^^^^^^^^^^^^^^^^^^^^^^^^^^^^^^^^^^^^^^^^^^^
Mar 05 07:43:12 time chronotron.py[1242]:   File "/opt/chronotron/i2c_lcd.py", line 30, in __init__
Mar 05 07:43:12 time chronotron.py[1242]:     self.write(0x33, self.type_command)  # init sequence: 0x03, 0x03
Mar 05 07:43:12 time chronotron.py[1242]:     ^^^^^^^^^^^^^^^^^^^^^^^^^^^^^^^^^^^
Mar 05 07:43:12 time chronotron.py[1242]:   File "/opt/chronotron/i2c_lcd.py", line 60, in write
Mar 05 07:43:12 time chronotron.py[1242]:     self.bus.write_byte(self.i2c_addr, hi_byte)
Mar 05 07:43:12 time chronotron.py[1242]: OSError: [Errno 5] Input/output error
Mar 05 07:43:12 time systemd[1]: chronotron.service: Main process exited, code=exited, status=1/FAILURE
Mar 05 07:43:12 time systemd[1]: chronotron.service: Failed with result 'exit-code'.

I am setting up without Python virtual environments as this is a dedicated NTP server. My cabling is as follows:

DISPLAY           Pi
GND                 GND
ACC                  5V
SDA                  SDA1
SCL                   SCL1

I think this is all correct, so I am not sure what the issue might be?

domschl, 2025-03-05:
did you try to run `python chronotron.py` from terminal to check without systemd services? And: did you enable i2c and check with ic2detect that the display is visible on the i2c bus? (see [adafruit help](https://learn.adafruit.com/scanning-i2c-addresses/raspberry-pi)

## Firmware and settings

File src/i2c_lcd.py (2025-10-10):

import time
import logging
import smbus
import copy


class LcdDisplay:
    """ Support for LCD displays using HD44780 display chips using
        I2C via either PCF8574 or MCP23008 (Adafruit way) I2C to GPIO converters
    """
    def __init__(self, sm_bus:int=1, i2c_addr:int=0x27, cols:int=20, rows:int=4, ada:bool=False, fast_lcd:bool=False):
        """
        smbus:int: should be `1` for all Raspbery PI (with exception of Raspberry 1)
        i2c_addr:int: default is 0x27 (used with most hardware), Adafruit uses 0x20 if no bridges soldered
        cols:int: currently always 20
        rows:int: currently always 4
        ada:bool: default False, use PCF8574 chip and pin-layout
                          True: use Adafruit MCP23008 and their specific pin-layout
        """
        self.log: logging.Logger = logging.getLogger("LcdDisplay")
        self.ada: bool = ada
        self.fast_lcd:bool = fast_lcd
        try:
            self.bus:smbus.SMBus = smbus.SMBus(sm_bus)  # Rev 1 Pi: 0, Rev 2 Pi: 1  # pyright:ignore[reportUnknownMemberType]
            self.active:bool = True
        except Exception as e:
            self.log.error(f"Cannot open LCD on I2C bus: {e}")
            self.active = False
            return

        try:
            self.bus.read_byte(i2c_addr)  # pyright:ignore[reportUnknownMemberType]
            self.log.info(f"Connected to display at i2c address {hex(i2c_addr)}")
        except:
            self.log.error(f"No device found at i2c address {hex(i2c_addr)}")
            self.active = False
            return
        
        self.i2c_addr:int = i2c_addr
        self.cols:int = cols
        self.rows:int = rows
        self.line_cmds:list[int] = [0x80, 0xC0, 0x94, 0xD4]  # lines 1-4

        # Communication timing for LCD display
        if self.fast_lcd is True:
            self.start_byte_delay:float = 0.0
            self.delay:float = 0.000001
            self.cls_delay:float = 0.0008
        else:
            self.start_byte_delay = 0.001
            self.delay = 0.00001
            self.cls_delay = 0.003
        
        self.type_data:int = 1
        self.type_command:int = 0
        self.enable:int = 0x04
        self.set_backlight(True)

        if self.ada is True:
            # If MCP23008 chip is used, initialize it. (PCF8574 doesn't need init)
            self._init_mcp23008()

        # Initialize the display chip HD44780
        self.write(0x33, self.type_command)  # init sequence: 0x03, 0x03
        self.write(0x32, self.type_command)  # init seq cont: 0x03, 0x02
        self.write(0x06, self.type_command)  # cursor dir
        self.write(0x0C, self.type_command)  # display on, cursor off, blink of
        self.write(0x28, self.type_command)  # data len, num lines, font size
        self.write(0x01, self.type_command)  # clear (slow!)
        time.sleep(self.cls_delay)

        # Initialize the display buffer
        self.screen_buf:list[list[str]] = [[" " for _ in range(cols)] for _ in range(rows)]
        self.cur_row:int = 0
        self.cur_col:int = 0
        
        self.log.debug("LCD display initialized.")

    def _init_mcp23008(self):
        # Taken from: <https://github.com/adafruit/Adafruit_CircuitPython_MCP230xx/blob/main/adafruit_mcp230xx/mcp23008.py>
        # and <https://github.com/adafruit/Adafruit_CircuitPython_CharLCD>
        if self.ada is True:
            self.bus.write_byte_data(self.i2c_addr, 0x00, 0x01)  # IODIR, reset almost all to OUTPUT, bit 0 input (unused)  # pyright:ignore[reportUnknownMemberType]
            time.sleep(self.delay)
            self.bus.write_byte_data(self.i2c_addr, 0x06, 0x00)  # GGPU, all pull-ups off  # pyright:ignore[reportUnknownMemberType]
            time.sleep(self.delay)
            self.bus.write_byte_data(self.i2c_addr, 0x01, 0x00)  # IPOL, no inverse polarity  # pyright:ignore[reportUnknownMemberType]
            time.sleep(self.delay)
            
    def set_backlight(self, state:bool):
        """ Set backlight on/off """
        if self.active is False:
            return
        if state is True:
            self.backlight:int = 0x08
        else:
            self.backlight = 0x00

    def _dev_write(self, byte:int):
        if self.ada is True:
            # Do a register-write for MCP23008, using GPIO function 0x09
            self.bus.write_byte_data(self.i2c_addr, 0x09, byte)  # MCP23008 GPIO function    # pyright:ignore[reportUnknownMemberType]
        else:
            # Just write content for PCF8574
            self.bus.write_byte(self.i2c_addr, byte)  # pyright:ignore[reportUnknownMemberType]
        
    def write(self, byte:int, data_type:int):
        """ write to Display chip using an I2C to GPIO converter """
        if self.active is False:
            return

        if self.ada is True:
            # 'cabling' between display chip and i2c convert is different for adafruit!
            backlight = self.backlight << 4
            data_type = data_type << 1
            hi_byte = data_type | ((byte & 0xF0) >> 1) | backlight
            lo_byte = data_type | ((byte & 0x0F) << 3) | backlight
        else:
            hi_byte = data_type | (byte & 0xF0) | self.backlight
            lo_byte = data_type | ((byte << 4) & 0xF0) | self.backlight

        time.sleep(self.start_byte_delay)
        self._dev_write(hi_byte)
        time.sleep(self.delay)
        self._dev_write(hi_byte | self.enable)
        time.sleep(self.delay)
        self._dev_write(hi_byte & ~self.enable)
        time.sleep(self.delay)

        time.sleep(self.start_byte_delay)
        self._dev_write(lo_byte)
        time.sleep(self.delay)
        self._dev_write(lo_byte | self.enable)
        time.sleep(self.delay)
        self._dev_write(lo_byte & ~self.enable)
        time.sleep(self.delay)

    def write_row(self, row:int):
        """ Write complete row from buffer """
        if self.active is False:
            return
        ra = self.line_cmds[row]
        self.write(ra, self.type_command)
        for i in range(self.cols):
            self.write(ord(self.screen_buf[row][i]), self.type_data)

    def print_row(self, row:int, text:str):
        """ Print row to buffer and display """
        if self.active is False:
            return
        if row < 0:
            row = 0
        if row >= self.rows:
            row = self.rows - 1
        text = text[: self.cols].ljust(self.cols, " ")
        self.screen_buf[row] = [text[i] for i in range(len(text))]
        self.write_row(row)

    def print_at(self, row:int, col:int, text:str):
        """ Print to buffer and display at given coordinates """
        if self.active is False:
            return
        if row < 0 or row > self.rows - 1:
            row = 0
        if col < 0 or col > self.cols - 1:
            col = 0
        text = text[: self.cols - col]
        for i in range(len(text)):
            self.screen_buf[row][i + col] = text[i]
        self.write_row(row)

    def scroll(self, n:int=1):
        """ Scroll screen a number of lines """
        if self.active is False:
            return
        for _ in range(n):
            for r in range(self.rows - 1):
                self.screen_buf[r] = copy.copy(self.screen_buf[r + 1])
            for i in range(self.cols):
                self.screen_buf[self.rows - 1][i] = " "
        for i in range(self.rows):
            self.write_row(i)
        if self.cur_row > 0:
            self.cur_row = self.cur_row - 1

    def print(self, text:str):
        """ Print longer text, scroll if necessary """
        if self.active is False:
            return
        if len(text) + self.cur_col > self.cols:
            ctext = text[: self.cols - self.cur_col]
            rtext = text[self.cols - self.cur_col :]
        else:
            ctext = text
            rtext = None
        if self.cur_row >= self.rows:
            self.scroll()
        for i in range(len(ctext)):
            self.screen_buf[self.cur_row][self.cur_col + i] = ctext[i]
        self.cur_col = self.cur_col + len(ctext)
        self.write_row(self.cur_row)
        if self.cur_col >= self.cols:
            self.cur_col = 0
            self.cur_row = self.cur_row + 1
        if rtext is not None:
            self.print(rtext)


if __name__ == "__main__":
    """ Stand-alone test routines for the display
        Adapt i2c_addr and adafruit_hw below
    """

    # Adapt:
    i2c_addr:int = 0x27         # I2C address, adapt to your board (usual values are 0x20 .. 0x27)
    adafruit_hw:bool = False    # Set to True for Adafruit MCP23008 based I2C converter, False for all others (PCF8574 converter)
    fast_lcd:bool = True        # True: Exceed documented timings for LCD for reduced latency
    
    # Start test:
    logging.basicConfig(level=logging.DEBUG)
    lcd = LcdDisplay(1, i2c_addr, 20, 4, ada=adafruit_hw, fast_lcd=fast_lcd)
    if lcd.active is True:
        if adafruit_hw is True:  #pyright:ignore[reportUnnecessaryComparison]
            print("Display (Ada) is active, outputting a test-text to the display...")  #pyright:ignore[reportUnreachable]
        else:
            print("Display is active, outputting a test-text to the display...")
        test_text:str = "Hello! That is a hell of a lot of text that we are going to display on this tiny screen. However there is always a way to present information in a way that is helpful, even under contrained conditions."
        start_time = time.time()
        lcd.print(test_text)
        dtc:float = (time.time()-start_time)/len(test_text)        
        print(f"Done, display speed per character: {dtc:1.8f} sec")
        exit(0)
    else:
        print("Failed to initialize display")
        exit(-1)

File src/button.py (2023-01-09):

import RPi.GPIO as gp
import time


class Button:
    def __init__(self, button_list, verbose=False):
        """array of [(pin, name),..]"""
        self.verbose = verbose
        self.button_list = button_list
        self.button_pins = [button[0] for button in button_list]
        gp.setmode(gp.BCM)
        gp.setup(self.button_pins, gp.IN, pull_up_down=gp.PUD_UP)
        for button in self.button_list:
            gp.add_event_detect(
                button[0], gp.FALLING, callback=self.button_pressed, bouncetime=250
            )

    def button_pressed(self, pin):
        for button in self.button_list:
            if pin == button[0]:
                if self.verbose is True:
                    print(f"{button[1]} at pin {button[0]} pressed!")
                button[2]()

    def cleanup(self):
        for button in self.button_list:
            gp.remove_event_detect(button[0])


if __name__ == "__main__":

    def button_blue():
        print("The blue func")

    def button_black():
        print("The black func")

    bt = Button([(27, "blue", button_blue), (22, "black", button_black)], True)

    while True:
        time.sleep(0.1)

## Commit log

2020-12-01 Antenna image
2020-12-01 Update README.md
    PPS connector
2023-01-09 drivers for 4x20 lcd
2023-01-09 more doc
    [gps_i2c.fzz]
2023-01-09 add i2c wiring
2023-05-17 rename exec() to prevent name-clash
    [chronotron.py]
2023-06-30 Example sources for 4x20 LCD, fixes #3
    Added some examples for the 4x20 LCD: Two parts are needed: the 4x20 LCD and a parallel to I2C converter backpack. They are sometimes sold as kit, sometimes separately.
2023-06-30 Backlight of LCD is switched off during the night.
2023-08-20 Raspberry Pi OS 64-bit timeout on PPS kernel bug
2023-12-20 Start of Raspberry Pi 5 updates
    PTP support, RTC support
2023-12-21 Rev 2 of display software: show stratum level, use logging stratum and time source changes, fixes #7
    [chronotron.py]
2023-12-21 Changes to backlight timer
2023-12-21 Fix stratum messages on start
    [chronotron.py]
2024-04-30 Serial Port changes with Raspberry Pi 5
    Added documentation changes for Serial Port Usage with Raspberry Pi 5, thanks @aGGreSSiv for the research.
2025-10-05 Use python3-gps, show fix and total sats
    [chronotron.py]
2025-10-05 Revert start/end time to match upstream
    [chronotron.py]
2025-10-05 Update README for Raspberry Pi OS changes to Trixie
2025-10-08 add i2c port-tests to display initialization
2025-10-08 i2c port check
2025-10-09 First trials for MCP33008 (Adafruit chip) support, fix typing
    [chronotron.py, i2c_lcd.py]
2025-10-09 Use correct register functions for MCP23008
    [i2c_lcd.py]
2025-10-09 Adapt chronotron for Adafruit's i2c chip mcp23008
2025-10-10 fix None crash for start/end_time
    [chronotron.py]
